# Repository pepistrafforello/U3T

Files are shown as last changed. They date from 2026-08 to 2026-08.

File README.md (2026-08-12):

# U3T — the Unnamed 3D Thingy

**A parametric generator, and its own verification suite, for a family of two-part solids that
look impossible from every side and come apart with a single movement.**

> There is a block made of two different kinds of wood, mated so perfectly that there is no air
> between them. From every side the assembly looks exactly the same: a seam at mid-height with a
> small dovetail key in the middle of each face. The two layers can be separated with one simple
> movement — no glue, no springs, no tricks. The same movement puts them back together. How?

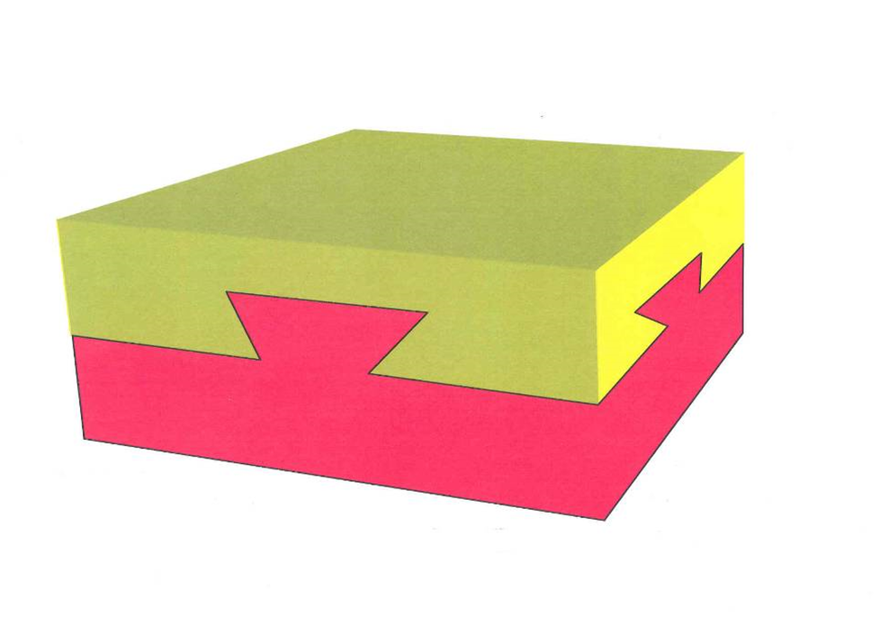
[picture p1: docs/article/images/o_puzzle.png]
The block, identical from all four sides


The dovetail on the front face says the top cannot be lifted. The dovetail on the side face says it
cannot slide sideways either. Every face you check makes the object more impossible — and yet the
answer is not unique: the puzzle has *infinitely many* solutions, and the interesting ones have
enough room left over to hide a message inside.

This repository holds the code that designs those objects, the code that proves the design is
correct, the print-ready STL files it produces, and the write-ups. The story is told in the
article: [`docs/article/medium-post.md`](docs/article/medium-post.md). The engineering is in
[`docs/The-Unnamed-3D-Thingy.md`](docs/The-Unnamed-3D-Thingy.md).

---

## The idea in one move: shear the world

Suppose the two halves separate by sliding along a fixed oblique direction **d** = (d₁, d₂, 1).
When is a proposed parting surface valid? Change coordinates so that **d** becomes vertical:

```
u = x − d₁·z        v = y − d₂·z        z = z
```

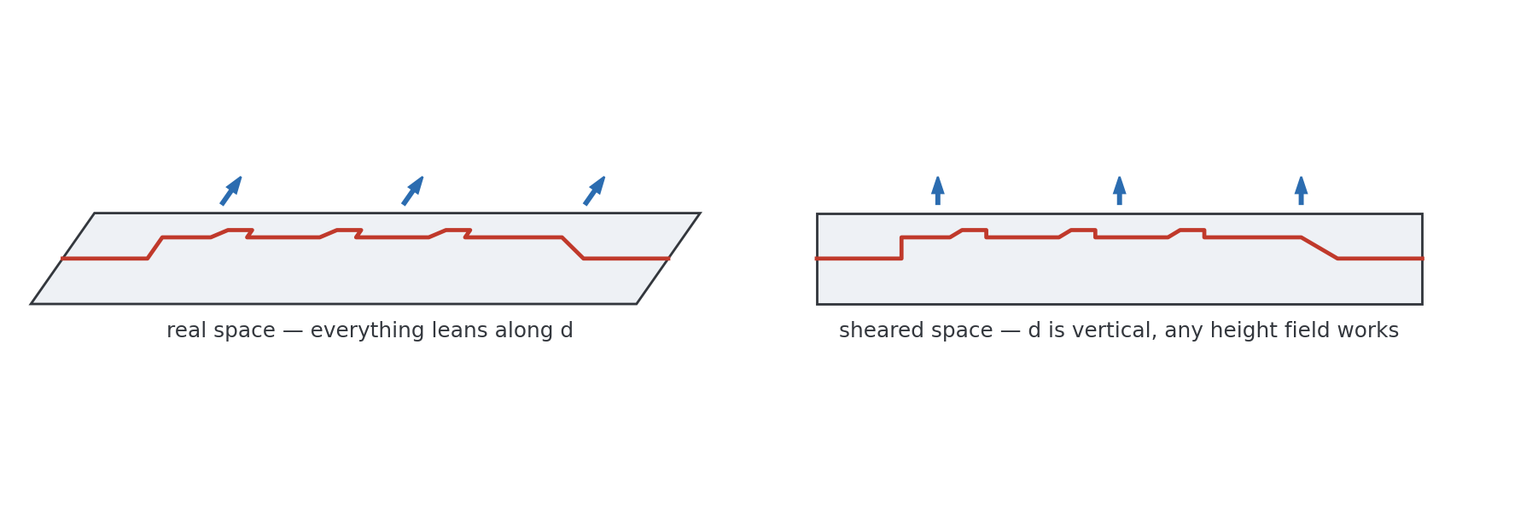
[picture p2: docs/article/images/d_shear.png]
The shear trick


In sheared space the separating motion is straight up, and a surface can be lifted off vertically
**exactly when it is a single-valued height field** — one z per (u, v), vertical cliffs allowed.
So: draw *anything* in the (u, v) plane, extrude it vertically, shear back. The walls come out
parallel to **d** automatically, and the two parts are separable by construction. No angle checks,
no trial and error.

Two consequences fall out of that one sentence:

* **Every side gets its own private groove.** Because **d** has a component along all three axes,
  each face carries an independent ramp instead of two grooves crossing the whole block — so the
  square is not special: any polygon with three or more sides works.
* **The middle of the block becomes free real estate.** Once the perimeter does the puzzle's work,
  the rest of the hidden interface can be arbitrary artwork: a title, a portrait, a QR code.

The shipped object uses that space for a graduation gift — a title, a subtitle, and a scannable QR
code, none of it visible from outside:

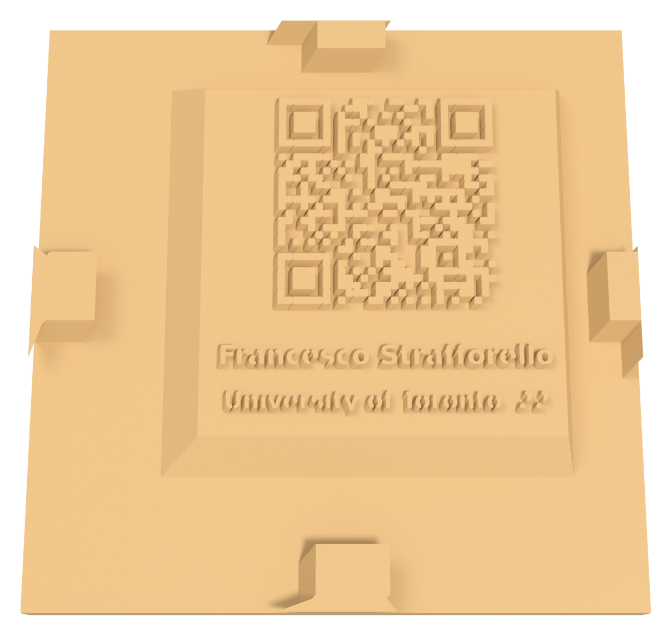
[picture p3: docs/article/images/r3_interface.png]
The hidden interface


---

## What is in this repository

```
u3t_generator.py        straight edition: builds both parts, then verifies them
u3t_rot_generator.py    rotation edition: same contract, opens by rotating about an external axis
dfm_scan.py             independent minimum-feature scan (the 0.5 mm FDM rule)
u3t_figures.py          figures for the technical document, straight edition
u3t_rot_figures.py      figures for the technical document, rotation edition

stl/                    the six meshes: two printable pairs, plus assembly-oriented copies
verification/           machine-readable verification reports (JSON), regenerated on every build

docs/
  The-Unnamed-3D-Thingy.md    the full write-up: theory, Fusion walkthrough, generator,
                              verification, printing, and the rotation chapter
  original-design-notes.pdf   the notes the project started from, years before it was finished
  figures/                    figures for the write-up (original/ = extracted from the PDF)
  article/medium-post.md      the article, in Medium's voice
  article/images/             its renders (Blender/Cycles) and diagrams (matplotlib)

tools/
  prep_shots.py           poses the verified STLs and emits the shot list
  blender_render.py       headless Cycles renderer for the photographic figures
  postprocess.py          flatten / crop / montage / sanity-check the renders
  diagrams.py             the clean 2D diagrams used by the article
  make_paste_html.py      article markdown -> HTML page you can paste into Medium
  extract_pdf_figures.py  re-extracts docs/figures/original/ from the PDF
```

Everything writes into `build/` (git-ignored) except the deliverables — STLs, reports, figures —
which land in their committed locations.

---

## Quick start

```bash
git clone https://github.com/pepistrafforello/U3T.git
cd U3T
python -m venv .venv
.venv\Scripts\activate          # Windows;  source .venv/bin/activate elsewhere
pip install -r requirements.txt

python u3t_generator.py         # straight edition: build + verify        (~10 s)
python u3t_rot_generator.py     # rotation edition: build + verify        (~25 s)
python dfm_scan.py              # minimum-feature scan of all four parts  (~45 s)
```

Each generator writes its STLs to `stl/`, its report to `verification/`, and prints the whole
verification suite as it goes:

```
bottom: watertight=True winding=True bodies=1 volume=89932 mm^3 ... -> PASS
top:    watertight=True winding=True bodies=1 volume=56138 mm^3 ... -> PASS
assembled overlap: 0.000000 mm^3 -> PASS
slide along d, t= 0.05: overlap=0.000000 -> PASS
...
slide along d, t=   40: overlap=0.000000 -> PASS
control (straight up), t=1.0: overlap=61.126 mm^3 -> PASS (locks)
control (flat diagonal slide), t=1.0: overlap=341.060 mm^3 -> PASS (locks)
```

Nothing else is needed to print the object — but if you want to regenerate the pictures too, see
[Reproducing the figures](#reproducing-the-figures-and-the-article).

---

## The two editions

Both are 100 × 100 × 15 mm, both show the identical dovetailed seam on all four faces, and both
hide the same interface. They differ only in the motion that opens them — which is the point: two
objects that are indistinguishable from the outside and refuse each other's solution.

| | straight edition | rotation edition |
|---|---|---|
| opening motion | translation along **d** = (0.7, 0.7, 1) | rotation of ≈ 12° about an external axis |
| axis / direction | 44.7° off vertical, diagonal in plan | direction (1, 1, 0)/√2 through (105, −105, −103.5) mm |
| walls | planar, parallel to **d** | patches of cylinders coaxial with the axis |
| generator | `u3t_generator.py` | `u3t_rot_generator.py` |
| print files | `stl/U3T_bottom.stl`, `stl/U3T_top_print.stl` | `stl/U3T_rot_bottom.stl`, `stl/U3T_rot_top_print.stl` |
| report | `verification/verify_report.json` | `verification/verify_report_rot.json` |

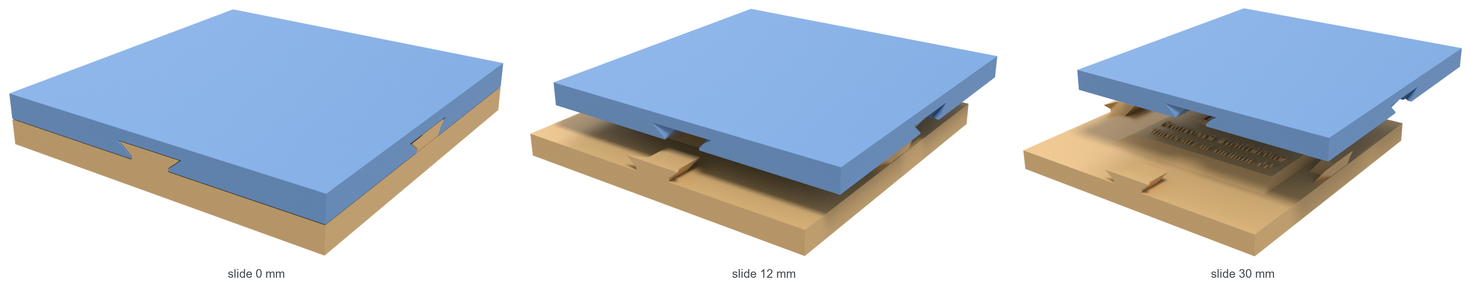
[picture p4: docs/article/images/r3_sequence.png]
Opening the straight edition


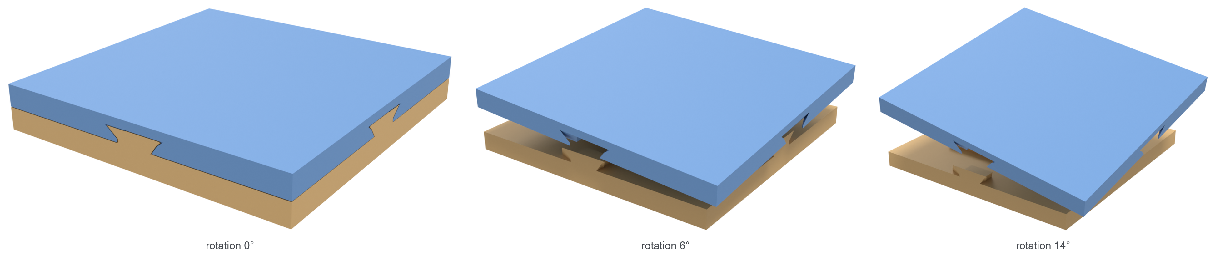
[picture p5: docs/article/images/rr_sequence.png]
Opening the rotation edition


The rotation edition needs three placement rules, all of which the generator's geometry satisfies
and the write-up derives:

1. the axis must run **diagonally in plan**, or orbit planes end up parallel to a face and grooves
   surface where they must not;
2. the **apex plane** — the vertical plane through the axis, where orbits turn around — must miss
   the block, otherwise a flat lid is visited twice by the same orbit and the parts jam (this is
   the silent failure that wrecked the original Blender attempt);
3. the axis must sit **far enough away** that every orbit slope stays printable.

---

## Design parameters

All of them live at the top of the generators, in millimetres. Change one, re-run, and the whole
object — including its proof — is rebuilt.

| parameter | shipped | meaning |
|---|---|---|
| `L`, `H` | 100, 15 | stock footprint and height |
| `SHX`, `SHY` | 0.7, 0.7 | the separation direction **d** = (`SHX`, `SHY`, 1) |
| `CLR` | 0.15 | clearance per part; total gap between the halves is 0.3 |
| `BAND_Z` | 7.5 | height of the seam on the side faces |
| `KEY_Z0`, `KEY_Z1` | 7.5, 11.5 | bottom and top of the dovetail key |
| `KEY_NECK_Z` | 8.3 | straight neck below the flare (manufacturability, see below) |
| `KEY_HW0`, `KEY_HW1` | 6.0, 10.0 | key half-width at the band and at the top (it flares → undercut) |
| `KEY_RAIL` | 8.0 | length of the internal anchor rail behind each key |
| `MIN_FEATURE` | 0.55 | minimum printable wall/stroke enforced on the interface artwork |
| `PLAT_*` | 7.0 … 11.0, ±30/34 | the plateau frustum that carries the payload |
| `QR_BOX`, `TITLE_BOX`, `SUB_BOX` | — | where the payload sits, in sheared plan coordinates |
| `QR_PAYLOAD`, `TITLE`, `SUBTITLE`, `SIGNATURE` | — | the content itself |

Two rules constrain the numbers, and both were learned the hard way:

* **Depth costs lean.** A key `h` mm tall can protrude at most `lean × h` from the face. A
  near-vertical **d** gives wafer-thin keys no matter how you draw them. At 0.7 the design sits
  right at the 45° overhang limit an FDM printer will bridge without supports — which is exactly
  where you want to be.
* **Anchor whatever the crop can orphan.** Each key continues inward as a solid rail, unioned in
  *before* the stock box crops the leaning prism. Skip this and the visible tabs become watertight,
  collision-free, and attached to nothing.

### Making your own

```python
# u3t_generator.py
QR_PAYLOAD = "https://example.com/album"   # shorter URLs -> coarser, easier-to-print modules
TITLE      = "Your Name"
SUBTITLE   = "Your Occasion"
```

then `python u3t_generator.py`. The verification suite re-runs on the new geometry, so a change
that breaks the puzzle property cannot pass silently. For a different polygon, edit the `faces`
table in `key_footprints()` — one entry per side, each with its inward plan direction; the theory
imposes no limit on the number of sides.

---

## Verification: the printed object cannot be flawed by luck

"Be accurate" means *do not trust the construction* — test the meshes that go to the printer. Each
generator attacks its own output before it exits, and writes the results to `verification/`.

| check | straight edition | rotation edition |
|---|---|---|
| bottom part watertight, consistent winding | yes — 89 932 mm³ | yes — 88 380 mm³ |
| top part watertight, consistent winding | yes — 56 138 mm³ | yes — 57 572 mm³ |
| **connected bodies per part** | 1 and 1 | 1 and 1 |
| assembly envelope | exactly 100 × 100 × 15 | exactly 100 × 100 × 15 |
| assembled overlap | 0.000000 mm³ | 0.000000 mm³ |
| overlap through the full opening motion | 0.000000 mm³ at 14 stations, t = 0.05 … 40 mm | 0.000000 mm³ at 12 stations, θ = 0.05° … 25° |
| **control** — pull straight up, 1 / 2 mm | collides: 61.1 / 102.8 mm³ | collides: 128.5 / 227.6 mm³ |
| **control** — flat diagonal slide, 1 / 2 mm | collides: 341.1 / 863.3 mm³ | collides: 416.3 / 926.1 mm³ |
| **control** — the *other* edition's move | — | collides: 282.1 mm³ (straight slide, 2 mm) |
| **control** — reverse rotation, 1° | — | collides: 21 424 mm³ |
| thin-feature scan (`dfm_scan.py`) | no free-standing feature below 0.5 mm | no free-standing feature below 0.5 mm |

The control rows are the puzzle property itself, measured rather than asserted: the naive motions
jam, and the one intended motion sweeps through the entire disassembly without ever touching. The
body-count row exists because it once failed — an early draft with a shallower **d** and no anchor
rails produced keys that were watertight, collision-clean, and *detached*. Watertightness says
nothing about a mesh being in one piece; counting connected components does.

---

## Manufacturability

Geometry can be provably correct and still contain features no nozzle can make. After a
manufacturability review flagged two of them, the generators enforce a minimum-feature policy:

* **Asymmetric clearance on the artwork.** A sliding fit does not need the gap split evenly. The
  raised side keeps its full nominal stroke width (never below `MIN_FEATURE` = 0.55 mm) and the
  cavity absorbs the whole 0.3 mm — otherwise the wall left standing between two neighbouring
  letter cavities can shrink to a tenth of a millimetre. Residual sub-minimum necks are removed by
  a morphological opening; sub-minimum walls between adjacent cavities are fused by a closing
  (`clean_thin`, `close_gaps`, `content_offset` in `u3t_generator.py`).
* **A straight neck under every flare.** The key lip starts only above `KEY_NECK_Z`, where its own
  depth already exceeds 0.55 mm, so the overhanging lip never feathers to nothing at its root.

`dfm_scan.py` re-checks this the way a print shop does — slice the part every 0.45 mm, erode each
slice by 0.249 mm, and report whatever disappears:

```bash
python dfm_scan.py
```

Both top parts come back completely clean. The bottom parts report a handful of patches, all of
them on the sloped edges where the key flanks meet the outer faces: those are tapering edges of
solid material, backed by full-thickness material immediately behind — a chamfer, not a wall. They
print as a slightly rounded lip edge, with no consequence for fit or strength. Every flush dovetail
outline in this family has them.

---

## Printing and assembly

* **Files** — print `stl/U3T_bottom.stl` as oriented and `stl/U3T_top_print.stl` (already flipped
  exterior-side-down); or the `U3T_rot_*` pair for the rotation edition. `U3T_top.stl` and
  `U3T_rot_top.stl` are the assembly-oriented copies, for CAD and inspection.
* **No supports.** The leaning walls sit at 44.7°, right at the classic FDM limit; the ramps are
  gentler; every relief faces up on the bed.
* **Settings** — PLA, 0.2 mm layers (0.12 mm makes a crisper QR), 3 perimeters, ≥ 15 % infill.
  Enable elephant-foot compensation (~0.1 mm) or deburr the first-layer edges: the band and the
  side faces have to mate flush.
* **Fit** — the 0.3 mm total gap is a snug sliding fit on a well-tuned printer. If it binds, sand
  lightly or rebuild with `CLR = 0.20`; for a loose demonstration fit use `CLR = 0.25`.
* **Assembly** — rest the top over the bottom offset by about +10 mm in x and y and lower it along
  the diagonal; it seats flush in one push. Because the lean of **d** breaks the square's symmetry,
  **only one of the four orientations engages** — the solver has to find the motion *and* the
  orientation.
* **The reveal** — relief QR codes scan best under raking light; a soft pencil rubbed flat across
  the module tops makes them scan instantly.

---

## Reproducing the figures and the article

The diagrams are matplotlib; the photographic figures are rendered headlessly in **Blender 5.x**
with Cycles, which has to be installed separately and reachable as `blender`.

```bash
python tools/diagrams.py                  # the 2D diagrams -> docs/article/images/
python tools/prep_shots.py                # pose the STLs -> build/posed, build/shots.json
blender -b --factory-startup -noaudio --python tools/blender_render.py -- \
        build/shots.json build/render_raw
python tools/postprocess.py               # flatten, crop, montage, check -> docs/article/images/
python tools/make_paste_html.py           # -> build/medium-post-paste.html
python u3t_figures.py                     # technical-document figures -> docs/figures/
python u3t_rot_figures.py
```

`postprocess.py` finishes with an automated check on every emitted image (minimum width, and a
non-white content fraction inside sane bounds) and prints `BAD: none` when they all pass.
`make_paste_html.py` produces a local page whose rich-text copy-paste lands cleanly in Medium's
editor, images included.

---

## Documentation

| document | what it is |
|---|---|
| [`docs/The-Unnamed-3D-Thingy.md`](docs/The-Unnamed-3D-Thingy.md) | the complete write-up: the original notes, the proof, a step-by-step Autodesk Fusion walkthrough, the automated pipeline, the verification suite, printing, and the rotation edition |
| [`docs/article/medium-post.md`](docs/article/medium-post.md) | the same story told as an article, for readers rather than builders |
| [`docs/original-design-notes.pdf`](docs/original-design-notes.pdf) | where it began: the unfinished notes, kept for provenance |

---

## Tested environment

Python 3.11.5 on Windows 11, with the versions pinned as comments in
[`requirements.txt`](requirements.txt). The heavy lifting is done by
[`manifold3d`](https://github.com/elalish/manifold) (guaranteed-watertight booleans),
[`trimesh`](https://github.com/mikedh/trimesh) and [`shapely`](https://github.com/shapely/shapely).
Nothing in the pipeline is platform-specific; the only external program is Blender, and only for
the figures.

## License

Apache License 2.0 — see [`LICENSE`](LICENSE). A small number of screenshots inside the original
design notes are third-party material and are excluded from that grant; they are itemised in
[`NOTICE`](NOTICE), together with the acknowledgements this project owes.

*The object still has a dovetail on every face, a motion nobody can see, a name hidden in the
middle — and, after all this time, no name of its own.*

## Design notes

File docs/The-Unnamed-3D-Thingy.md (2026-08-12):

# The Unnamed 3D Thingy

*Design notes — completed edition. Parts 1–4 are the original notes (text unchanged, figures re-extracted).
Parts 5–13 complete the project: the theory of why the construction works, a verified reference design,
step-by-step instructions for Autodesk Fusion, an automated generator, and print-ready STL files that have
been checked for correctness by simulation.*

---

## Part 1 — The puzzle (original notes)

Years ago, my boss shared with me a book he wrote, in digital format; its main topic is critical
thinking training. There is a section about a mental exercise, that I am summarizing as follows:

There is a block composed of two different types of wood, each about an inch in height, that
were mated in a manner that ensured no gaps of air between them. From every side, the
assembly looks the same:

The block, identical from every side

The two layers of wood can be separated from each other by a single simple movement, there
is no glue or any other adhesive or mechanical inhibitor involved. They could be reunited with
the same type of motion.

In the book, the solution to this puzzle is exactly the one beautifully designed by Roger:

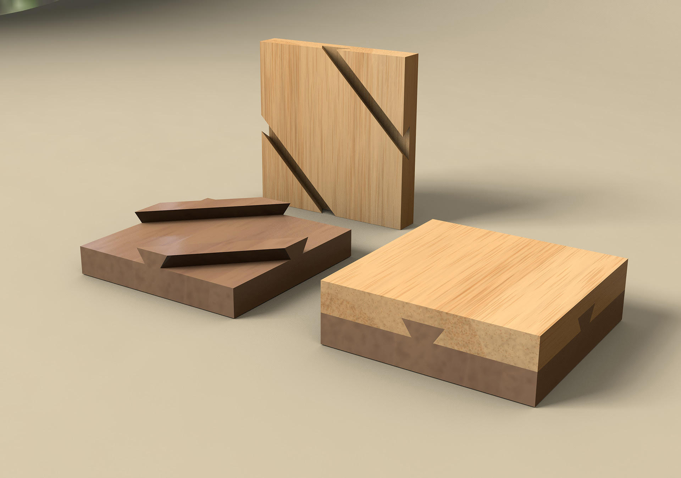
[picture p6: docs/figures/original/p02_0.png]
Roger's solution, exploded


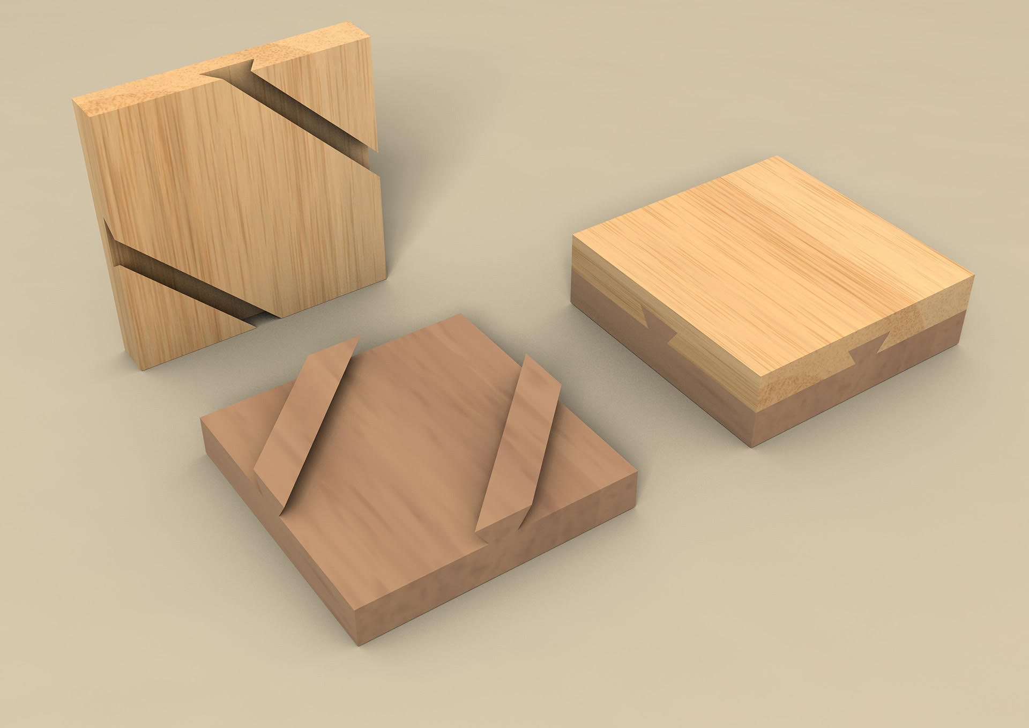
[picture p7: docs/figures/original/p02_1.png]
Roger's solution, second view


(I really love it!)

My observation back then, which I rummaged a bit more over time, is that this is not *the
solution*, because in fact the problem admits infinite solutions. To prove it, I created a different
one using 3D Builder on Windows, I had it 3D printed and gave it to my boss around Christmas
as a "semi-parting" gift, as he is semi-retiring:

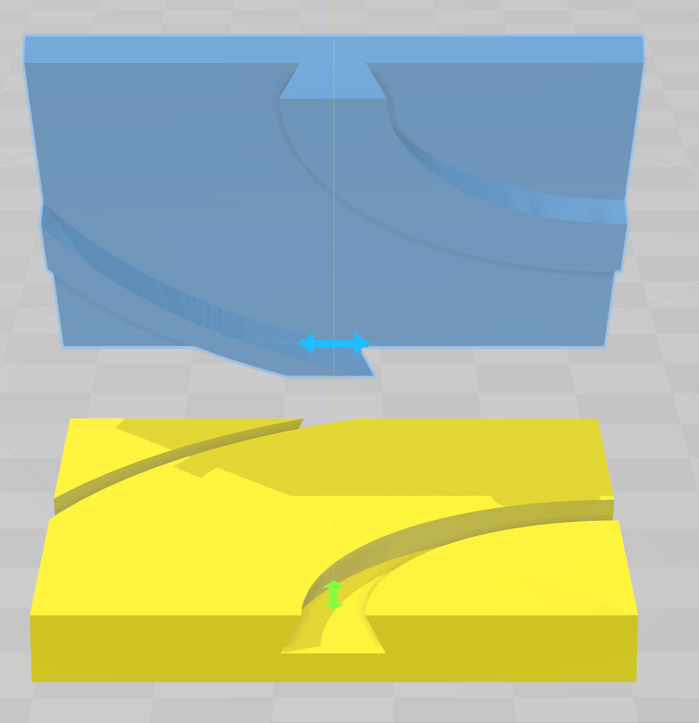
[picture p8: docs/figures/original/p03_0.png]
My curved-groove solution


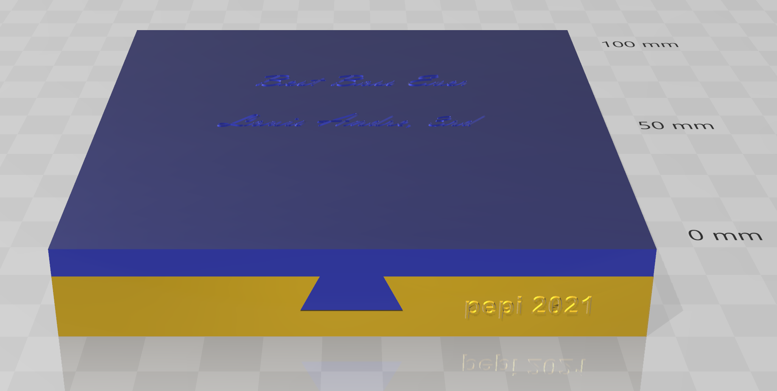
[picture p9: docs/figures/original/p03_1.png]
The printed gift, assembled


As it can be easily verified, Roger's solution and mine belong to a family of solutions which
consist of two grooves each connecting one of the side keys to another, where the center of the
curve that they describe can be arbitrarily set from somewhere between the middle of the
square and one of the corners, then to a corner (as in my solution), then beyond the corner
all the way to infinity (Roger's solution).

There are of course infinite solutions in this family, but they are still very much limited in their
shape; in particular, there is no additional information that can be encoded in the shape itself.

## Part 2 — The generalized method (original notes)

After giving it a bit of thought, I found out that we can do much better than that.
In fact, any amount of information, such as, for instance, QR codes or Roger's portrait, can be
encoded *inside* the apparatus without violating the requirements. Furthermore, the method can
be extended from four to any number of sides ≥ 3.

In a nutshell, the process is as follows:

- define a base shape for the half side *(original image lost from the PDF — see the dimensioned
  profile in Part 7, which plays the same role)*
- mirror it to generate a full side
- compose the sides to build the "polygon box" of choice, a square in this example but of
  course it can be anything ≥ 3

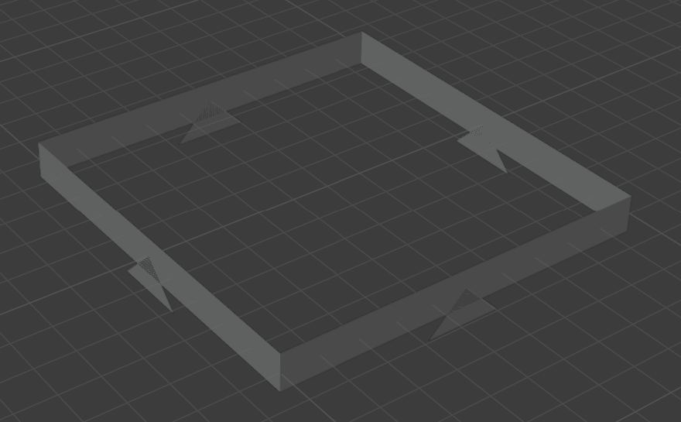
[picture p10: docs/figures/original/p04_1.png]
The polygon box


- extrude the box along a line with constant curvature, which can be arbitrary with some
  constraints, e.g. it cannot lie on a plane that is parallel to any of the sides. In this
  example, the extrusion is carried out along a straight line that is not parallel to any of the
  axes of the square prism, but it could be any other from an infinity of possible curves

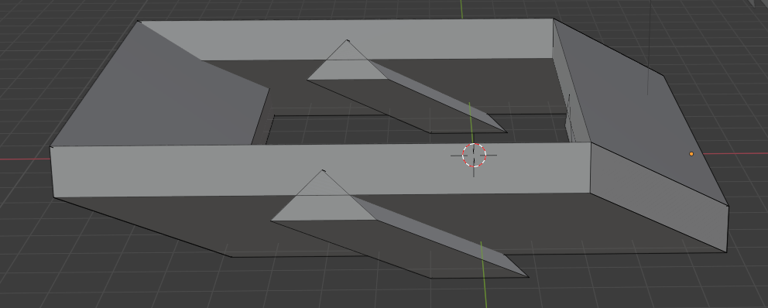
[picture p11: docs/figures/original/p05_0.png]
The extruded box


- compose the 3d boundary box for the complete assembly, that is, a prism that matches
  the contour of the "polygon box" and extends to surround the volume of the missing
  element
- crop the extrusion using the boundary box

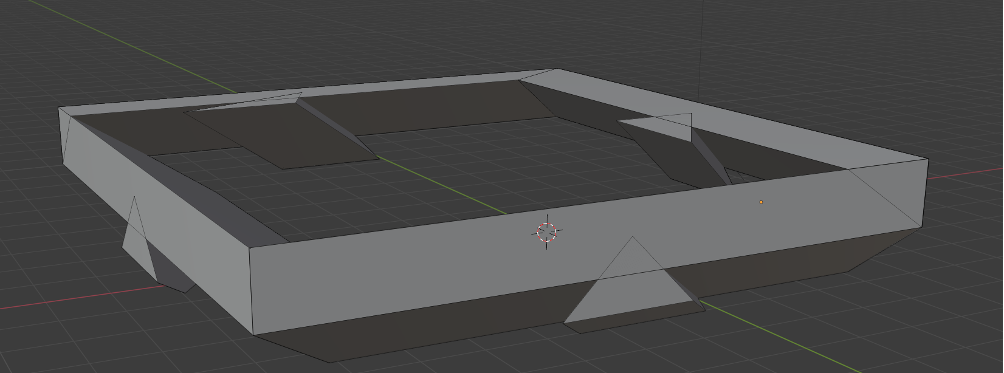
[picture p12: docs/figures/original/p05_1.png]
The cropped extrusion


Now, all the mandatory features are implemented; all we are left to do is to place a "lid" on top of
the box, and then create the complementing part by filling the space below. That means that we
still have a lot of degrees of freedom in designing the rest of the boundary between the two
parts, and thus we could encode an arbitrary amount of information there.

The key difference between this method and the solutions mentioned at the beginning of the
document is that, by moving along three axes instead of two, we were able to give each side its
own independent groove, which in turn makes it possible to change arbitrarily the number of
sides.

Putting it all together, I built a quick complete example using Blender up to the step above, and
then assembling it with 3D Builder, using .stl for the exchange:

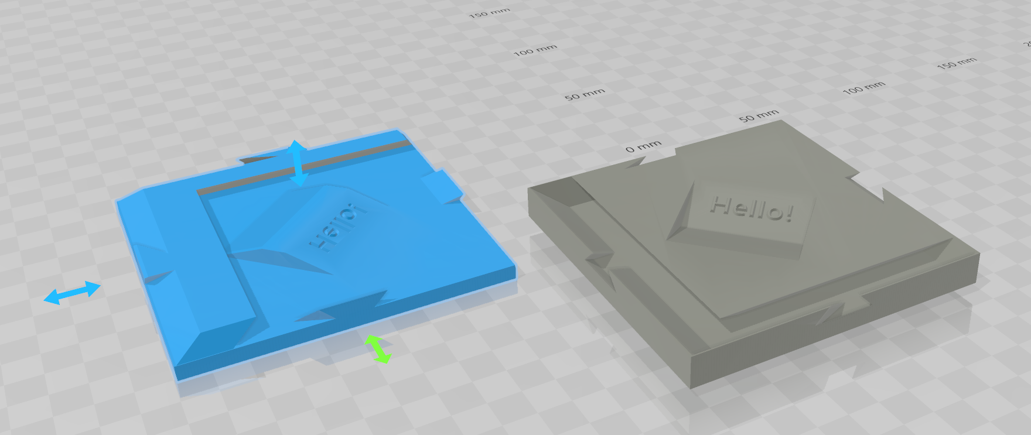
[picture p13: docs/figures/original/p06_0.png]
Hello example, parts


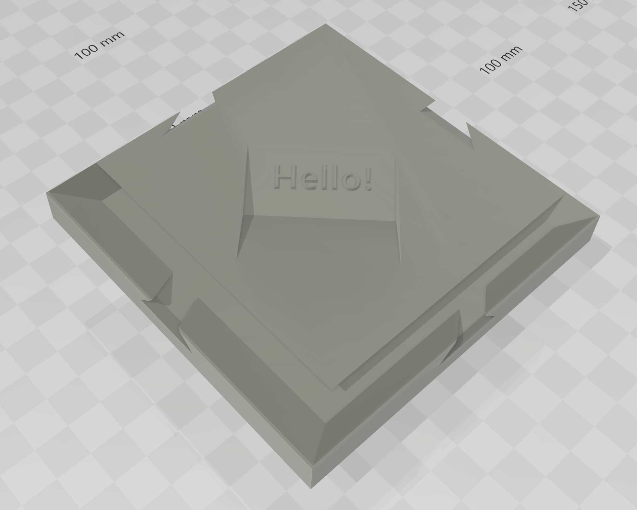
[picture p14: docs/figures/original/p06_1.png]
Hello example, assembled


## Part 3 — A graduation U3T ("Unnamed 3D Thingy") for Francesco (original notes)

Based on the above, we have a little project for the upcoming graduation in the family — I know, it
sounds impossible! I wonder, could it be reused elsewhere? ;)

The basic idea: starting from the "Hello" design in the previous page, adding two enhancements:

- Carrying out the extrusion of the "polygon box" along a nice, creative curve instead of a
  predictable and boring straight line
- Maximize use of the available space in the box, including the following elements:
  - A nice title "Francesco Strafforello"
  - Subtitle "University of Toronto '22"
  - QR code (will point to a family album online)
  - (only if feasible) other cool geometric elements TBD
- To account for engineering tolerance, we create two slightly different matrices, inner and
  outer (I'd rather stay out of gender references)

**1 — matrix.** The dimensions of the final product will be mm 100×100×15. Construct using 3D Builder.

Tolerance guidance (from Xometry handbook):

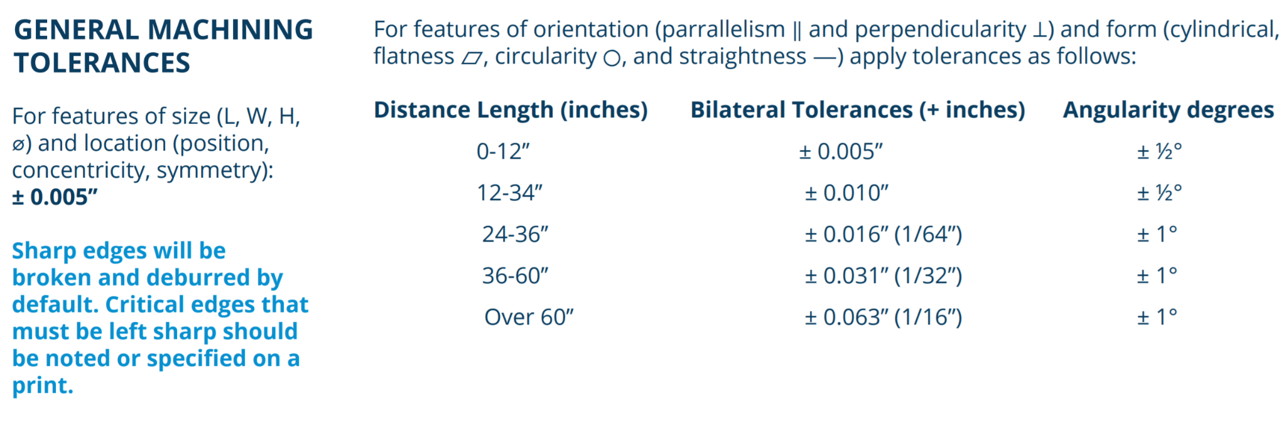
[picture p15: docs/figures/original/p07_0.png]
Xometry general machining tolerances


Given the dimensions of our project, it seems that applying a tolerance of ± 0.005" = 0.127 mm
everywhere might work.

To introduce tolerance, we modify the construction process described above. While we were
going through the extrusion process for one of the mating parts, and filling the remaining space
to obtain the other one, now we are going to extrude the tolerance space, and then using the
free space on either side to obtain the actual parts. With that in mind, we start by creating the
matrix as the difference between the inner and the outer one.

Inner matrix:

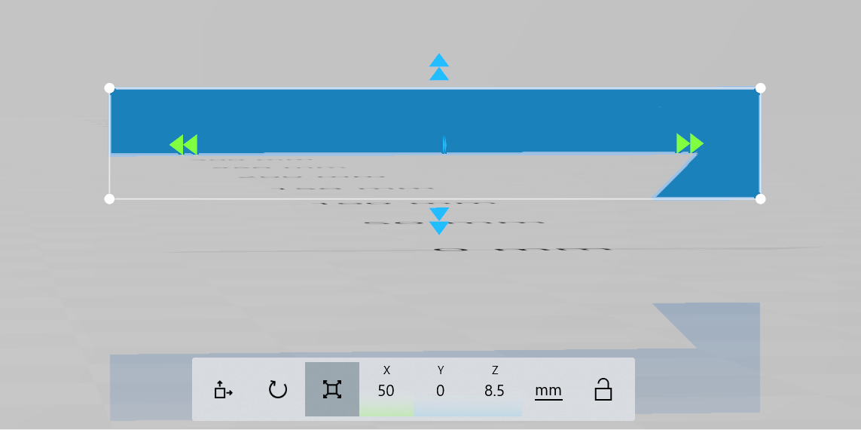
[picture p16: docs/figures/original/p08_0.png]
Inner matrix


Outer matrix:

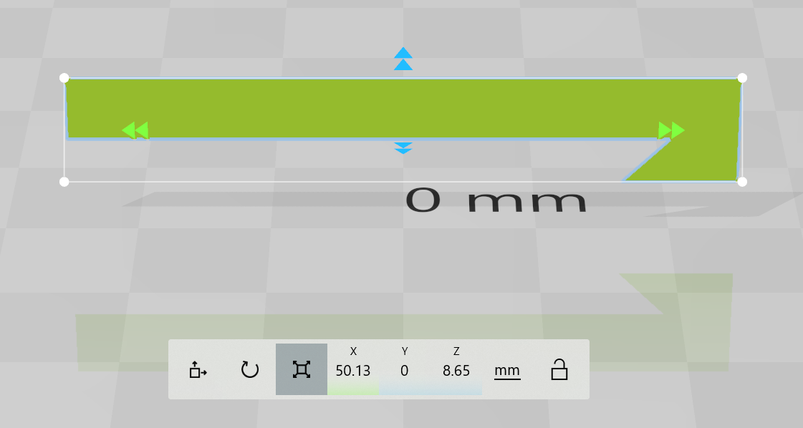
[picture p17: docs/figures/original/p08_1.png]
Outer matrix


The difference in the longer side (0.15 instead of 0.127) is adopted to make extra room for
diagonals and various curves.

In the end, the new matrix is simply composed of three thin rods joined together:

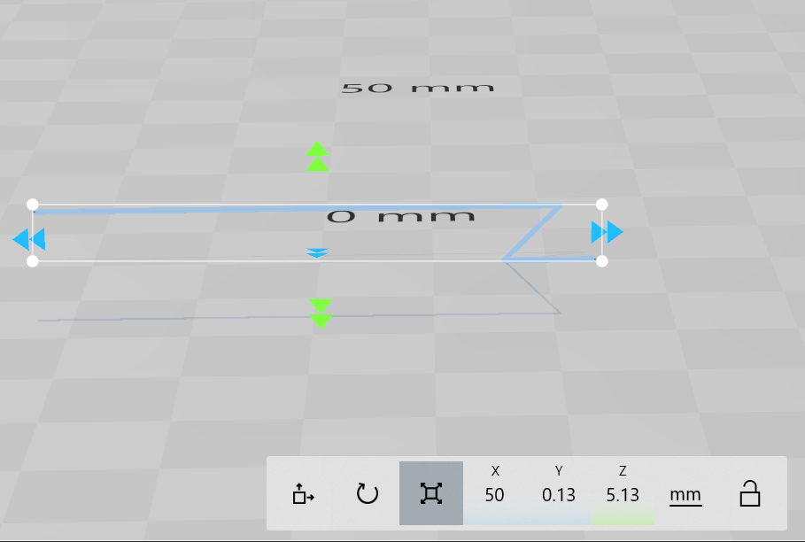
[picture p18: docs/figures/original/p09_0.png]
Matrix rods


And this is our "polygon box" — that is, the apparatus before the extrusion:

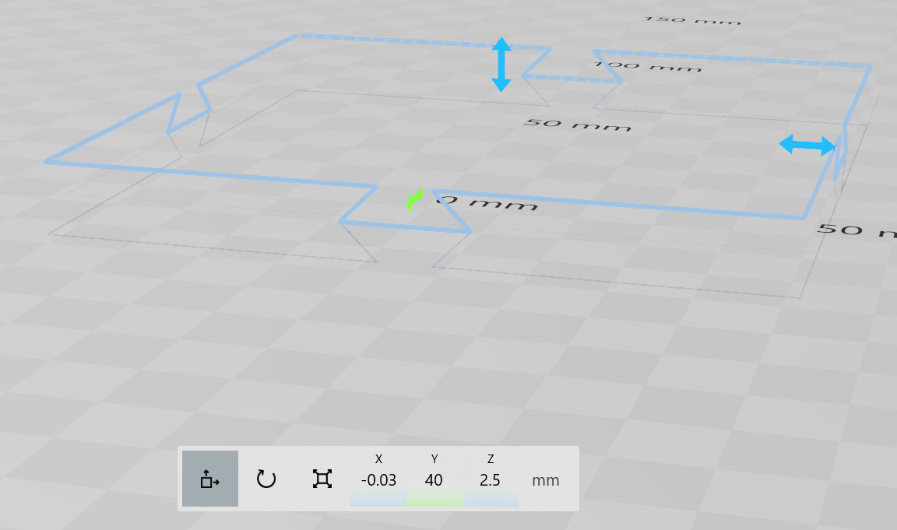
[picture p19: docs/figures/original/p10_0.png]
Polygon box wireframe


## Part 4 — The Blender attempt (original notes)

Thus far, I have used 3D Builder. Now I export the model in .STL format, to perform the
extrusion with Blender. After a few attempts, I found that rotating the polygon box and applying
the screw modifier along an external object I could get a nice, curved surface (external object is
the elongated cuboid in the background):

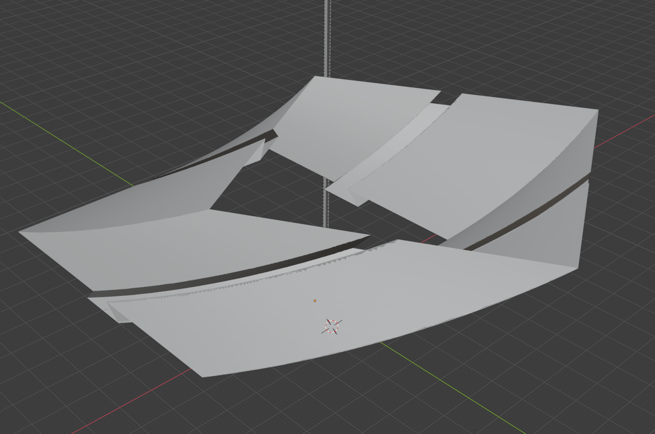
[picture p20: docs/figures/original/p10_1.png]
Screw-modifier extrusion in Blender


After exporting the component to .stl, and importing it back to Builder 3D we can obtain this
scene:

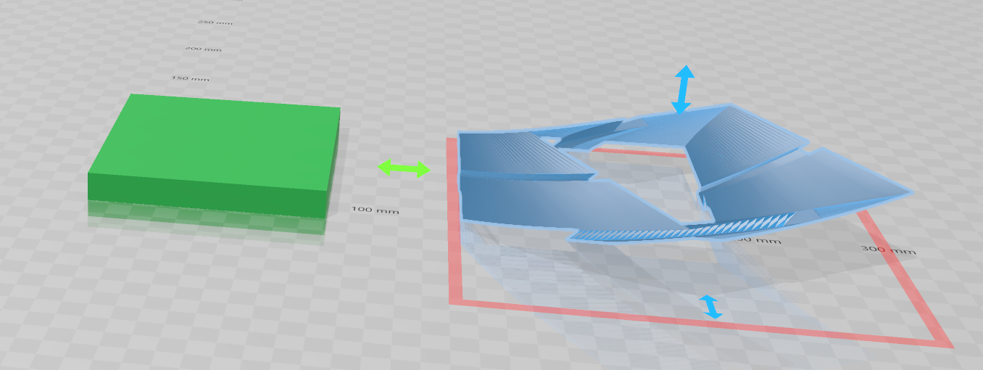
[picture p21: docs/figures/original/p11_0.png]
Back in 3D Builder


The green cuboid is the final volume for the apparatus, the blue one is the imported artifact.
Note the red square around it, something in its geometry seems to be problematic for 3D
Builder; but, activating the "Repair" function actually alters its geometry. I'm trying to go ahead
as it is, everything seems to be working so far. Checking out the intersection of the two artifacts:

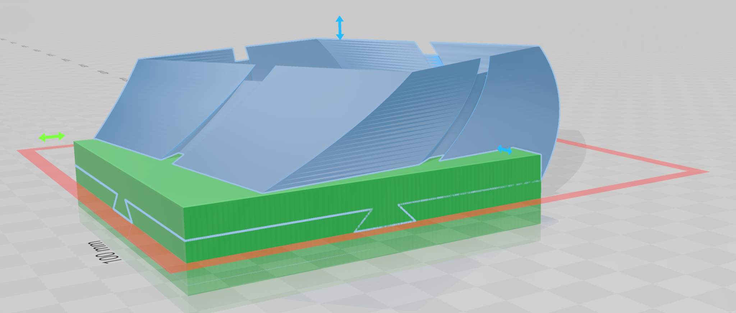
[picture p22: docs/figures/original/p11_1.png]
Intersection check


Everything seems to be correct from the opposite side as well:

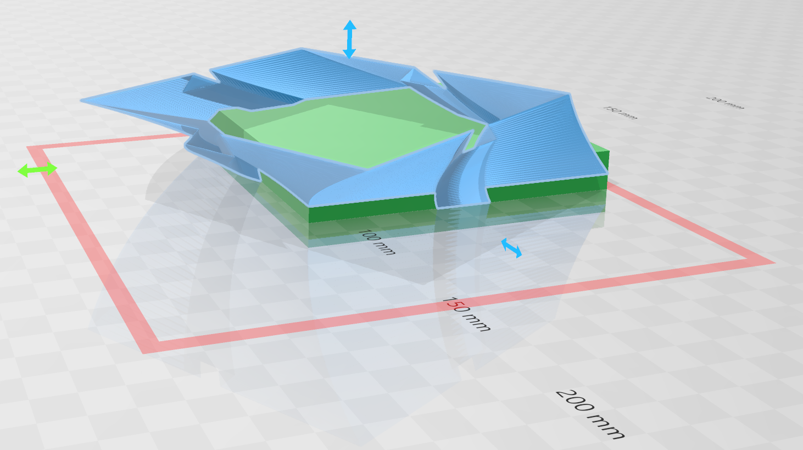
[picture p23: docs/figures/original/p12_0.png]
Opposite side check


Next step: I need to add a bottom to my "cutting box" — the blue shape, that is.
The bottom is where I want to add some hidden information — in this case, a QR code pointing to
Francesco's LinkedIn profile. I generated the QR code using QRmonkey.org, but I could have
used the sharing feature in Chrome, etc., then I loaded it in 3D Builder and gave it a bit of 3D
relevance (see https://www.youtube.com/watch?v=plvNbWHi84Y)

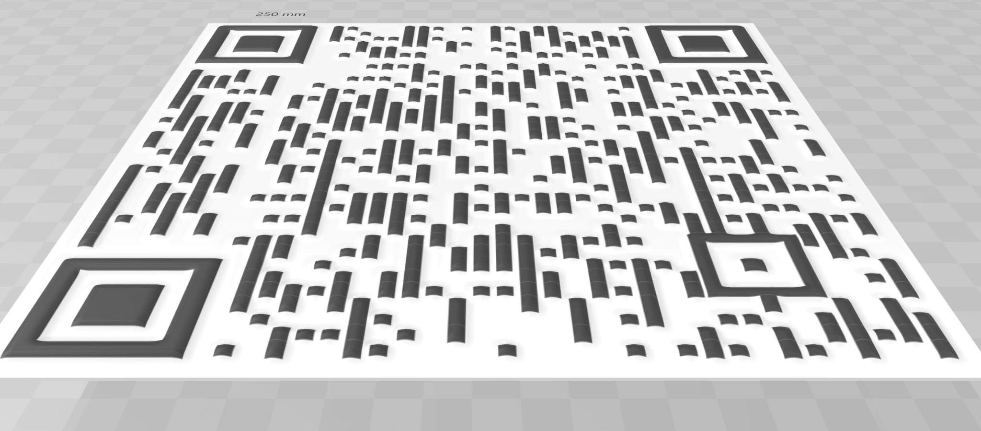
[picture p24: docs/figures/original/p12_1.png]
QR code with relief


I am making sure that the angles of the 3D features in the bottom QR-code image need to be
flatter than whatever angles will come from the "cutting box":

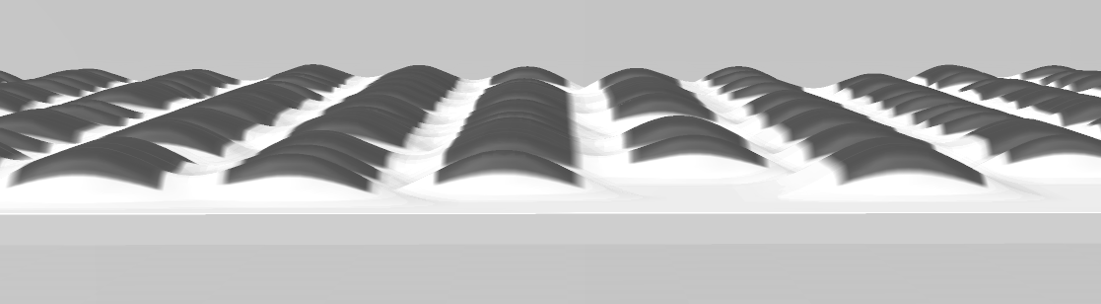
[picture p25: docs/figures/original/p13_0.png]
QR relief profile


Working inside 3D Builder I was able to join the bottom with the QR code and the cutting artifact,
but I could not manage to cleanup the material in excess from the bottom:

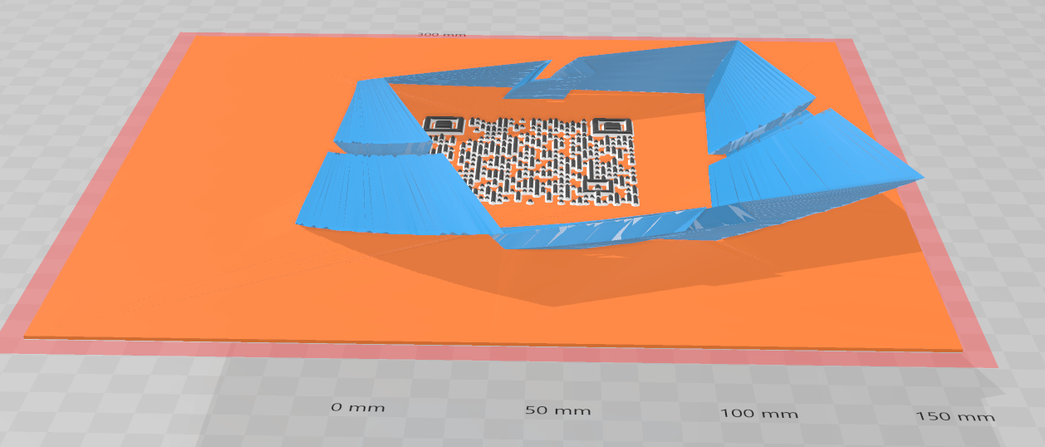
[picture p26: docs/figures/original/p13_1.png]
Excess material problem


So I exported the shape to STL and loaded it in Blender.

Then, with some hours of mesh work in Blender, I completed the cutting box which now includes
the bottom with QR code:

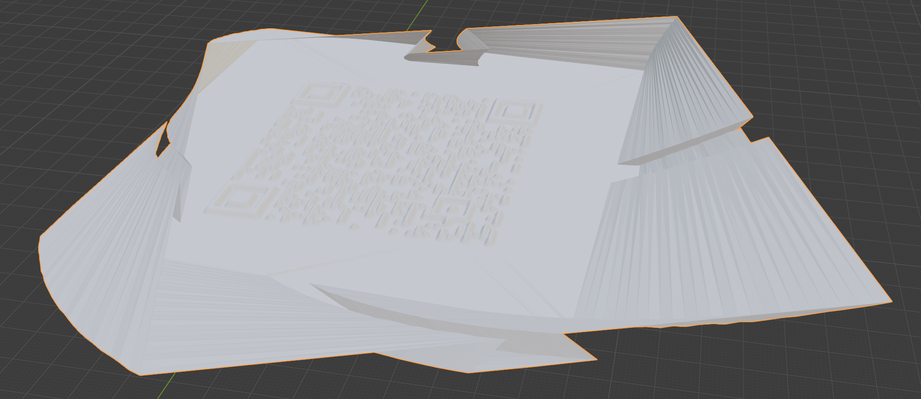
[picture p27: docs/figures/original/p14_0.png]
Completed cutting box


Since this shape has been entirely generated using a base shape that has a slightly larger width
than the known material tolerance, I can hope that removing it from the base box I will get two
mating parts; of course, the mesh is always an approximation but I can hope that in the worst
case I'll have to sand them a little.

OK, I'm saving this one just because I think it is cool:

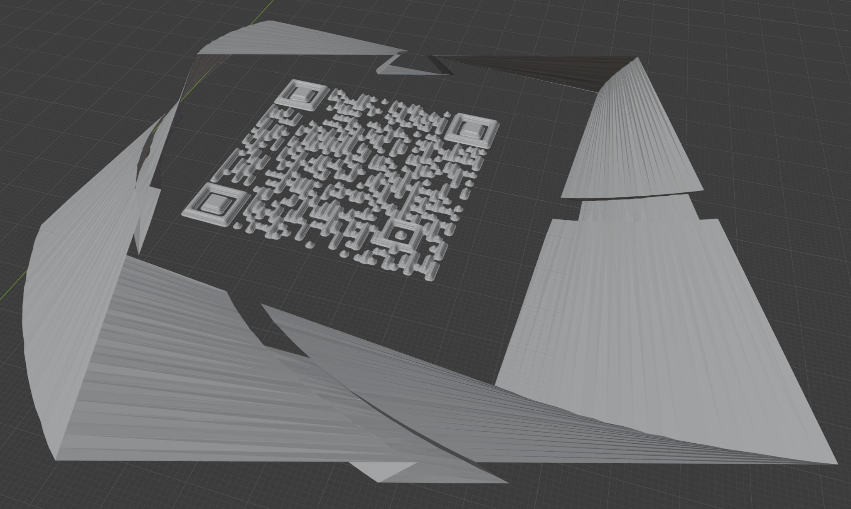
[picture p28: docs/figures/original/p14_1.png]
The cool one


---

*The notes stopped here. Everything below completes them.*

---

## Part 5 — What was still missing

The notes ended with a cutting box that "should" work, plus three open problems:

1. **No proof.** "I can hope that removing it from the base box I will get two mating parts" — hope,
   not verification. Nothing guaranteed that the two parts actually separate with one movement,
   or that they even come out as two valid solids.
2. **Fragile pipeline.** The Blender screw modifier produces an *open* surface (its ends are not
   capped), which is why 3D Builder drew the red warning frame and why "Repair" altered the
   geometry: repair tools cap and re-mesh non-manifold shells, changing the shape in the process.
   Hours of manual mesh work sat between the idea and a printable object, and every manual step
   could silently break the mating property.
3. **A hidden geometric trap.** The rule of thumb "features in the bottom must be flatter than
   whatever angles come from the cutting box" is necessary but **not sufficient** — see Part 12.
   With the screw-swept box of Part 4, a *flat* QR bottom is in fact not exactly separable near the
   plane through the screw axis; that is the subtle reason the manual assembly kept feeling harder
   than it should have been.

The completion below replaces hope with a construction that is correct *by construction*, and then
double-checks the result by simulating the disassembly motion on the final meshes.

## Part 6 — Why it works: one rule, one trick

**The rule.** Suppose the two parts separate by translating the top part along a fixed direction

> **d** = (d₁, d₂, 1)   (for example d = (0.7, 0.7, 1), about 45° off vertical)

Then the whole boundary between the two parts — the *parting surface* — must be visible "from
direction **d**": every straight line parallel to **d** must cross it at most once (crossing it along a
whole segment is also fine — that is a wall parallel to **d**, a sliding face). If some line parallel to
**d** entered the bottom part, left it, and entered it again, the top part would hook into the bottom
part and no translation along **d** could free it.

**The trick.** Instead of checking that rule surface by surface, change coordinates so it becomes
trivial. Define the **sheared coordinates**

> u = x − d₁·z    v = y − d₂·z    (z unchanged)

This shear maps every line parallel to **d** to a *vertical* line. So the rule becomes: *in sheared
coordinates, the parting surface must be a single-valued height field z = F(u, v)* — any height
field, with jumps allowed (a jump becomes a wall parallel to **d**, i.e. a sliding face).

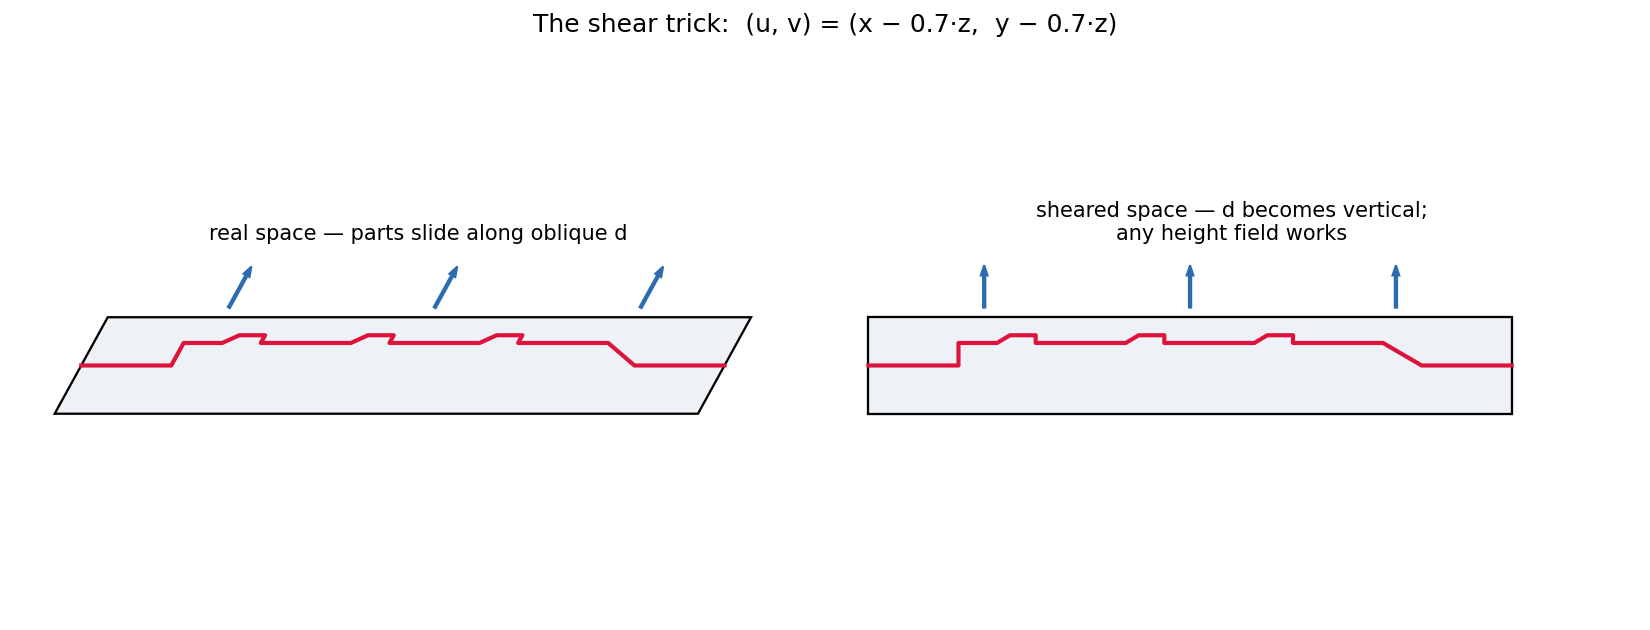
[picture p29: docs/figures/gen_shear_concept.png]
The shear trick


That single sentence is the entire theory of the U3T, and it proves the two claims from Part 2:

- **Arbitrary information can be encoded.** Any grayscale image whatsoever, interpreted as a
  height field in sheared coordinates, is a valid parting surface: QR codes, portraits, text —
  literally anything. Design your relief flat, shear it, done. In particular any artwork **extruded
  vertically in sheared space** (vertical walls become walls parallel to **d**) is separable *by
  construction* — no angle checking needed, ever.
- **Any number of sides ≥ 3 works.** The side keys are just more entries in the height field. The
  only constraint on **d** is the one already guessed in Part 2: **d** must not be parallel to any side
  face (its horizontal projection (d₁, d₂) must avoid the n side directions), so that every key
  actually withdraws *out of* its face instead of scraping along it.

And it explains the original two-groove family as the special case where the motion is horizontal
(a rotation about a vertical axis, or a straight slide as in Roger's): with no vertical component,
each groove must run all the way from one side to another, which is exactly why that family
carries no free space for information. Adding the third axis is what buys the freedom.

**Two robustness rules the height-field picture also gives us:**

- **Depth costs lean.** Anything that protrudes above the band *and shows on a side face* — the
  dovetail keys — can only be as deep (into the body) as `lean × height`: a key h mm tall can
  protrude at most `|(d₁,d₂)| × h` millimetres inward before the sliding motion would shear it
  off. A near-vertical **d** therefore produces wafer-thin keys no matter how they are drawn.
  With d = (0.7, 0.7, 1) and a 4 mm key, the tab is a solid ~2.8 mm deep — and 0.7 per axis is
  also the practical ceiling, because the leaning walls print at ~45°, the classic FDM limit.
- **Anchor what the stock crops.** Near the perimeter, the vertical columns of sheared space enter
  the block through a *side face*, not through the floor. A protruding feature there (a key tab)
  can end up connected to nothing once the stock box crops its leaning prism — it becomes a
  watertight but *floating* fragment, invisible to most mesh checks. The fix is structural: run
  every key tab into an **interior anchor rail** (same width, several mm inward, unioned before
  the clearance offset), so the visible tab is just the end of a solid internal rail — exactly
  like the tongue of a real sliding dovetail. And always verify the **body count**: each finished
  part must be one connected solid (Part 10).

## Part 7 — The reference design

The verified object completes the Part 3 project (straight extrusion line; for the "nice, creative
curve" upgrade and its extra constraint, see Part 12). All values are parameters and can be changed.

| parameter | value |
|---|---|
| stock | 100 × 100 × 15 mm |
| extrusion direction **d** | (0.7, 0.7, 1) — 44.7° from vertical, at the FDM 45° print limit |
| seam band height | z = 7.5 mm on all four faces |
| key (per face, centered) | trapezoid: 12 mm wide at the band, 20 mm at the top, 4 mm tall — solid tab ~2.8 mm deep; a 0.8 mm straight neck precedes the flare so the lip is ≥ 0.55 mm deep everywhere (DFM) |
| key anchor rail | 12 mm wide × 8 mm inward run per key, flat top at z 11.5 (Part 6 rule) |
| plateau | 45° (sheared) ramps from 68×68 @ z 7 to 60×60 @ z 11 |
| QR code | 29×29 modules, 1.24 mm/module, relief +1.2 mm, payload `Congratulations Francesco! UofT '22` |
| title / subtitle | relief +1.0 mm, DejaVu Sans Bold |
| clearance | ±0.15 mm per part (0.3 mm total gap) |
| signature | "pepi 2026", engraved 0.6 mm in the underside, mirrored to read from below |

The face profile — the "base shape for the half side" of Part 2, now dimensioned. The key belongs
to the bottom part and **flares upward**, so a straight vertical pull is impossible on every face,
while the flat band hides everything else. On the face the key merges with the bottom layer over
its full base width (it is the end of its internal anchor rail), exactly like a real dovetail:

Face seam profile

The parting surface, laid out as a plan in sheared coordinates. Each face key projects to a
quadrilateral just *outside* the z = 0 footprint (its prism leans back in through the face) and
continues inward as its anchor rail; QR and text are just black-and-white artwork dropped into
the plan:

Sheared-plan layout

The resulting bottom part, and the interface it hides:

Bottom part

Hidden interface from above

The top part is the exact complement (shown flipped, as it prints):

Top part, flipped

Assembled, exploded, and the single separating movement:

Assembled

Exploded along d

Separation sequence

From every side, the classic look — a mid-height seam with a small dovetail, identical on all four
faces (the 0.3 mm clearance shows as the thin joint line, as on any printed puzzle):

Four sides

A cross-section through the middle shows the whole mechanism at once — band, the two keys leaning
along **d**, plateau ramps, QR relief, and the uniform gap:

Cross-section

## Part 8 — Step by step in Autodesk Fusion

The construction from Part 6, translated to Fusion features. The strategy: model the **"Lower" solid**
(everything below the parting surface) once, parametrically, with a signed offset parameter `ofs`;
then obtain each part with one Combine against the stock box, evaluating `ofs` at −0.15 for the
bottom part and +0.15 for the top part.

**8.1 Setup**

1. New design, units mm. In **Modify ▸ Change Parameters** create user parameters:
   `L = 100`, `H = 15`, `band = 7.5`, `keyH = 4`, `keyW0 = 12`, `keyW1 = 20`,
   `dx = 0.7`, `dy = 0.7`, `railLen = 8`, `ofs = -0.15`.
2. **Stock**: sketch an L × L square on the XY plane, corner at the origin; Extrude `H`.
   Rename the body `Stock`.
3. **The direction path**: create a 3D sketch (Sketch ▸ Create 3D Sketch), draw a single line from
   `(-8, -8, -20)` to `(dx*40+8, dy*40+8, 40)` — a line along **d** extended well beyond the stock.
   Rename it `Path`. *Every* sweep in this recipe uses this one path; that is what guarantees all
   features share the same disassembly motion.

**8.2 The Lower solid**

4. **Base slab**: offset plane at z = −5; sketch a rectangle from (−30, −30) to (L+30, L+30);
   Extrude up to a height of `band + ofs − (−5)`, i.e. distance `band + ofs + 5`, as a **New Body**
   named `Lower`.
5. **Keys** (four sweeps, one per face):
   - Sketch on the front face plane (the XZ plane): draw the key trapezoid centered at x = L/2 —
     width `keyW0` at z = `band`, width `keyW1` at z = `band + keyH`. Apply a sketch **Offset** of
     `ofs` to the trapezoid (outward for positive).
   - **Create ▸ Sweep**, profile = the trapezoid, path = `Path`, extent: whole path, operation
     **Join** to `Lower`. The sweep makes the key an oblique prism along **d**; everything
     falling outside the stock is discarded later by the final Combine.
   - Repeat on the right, back and left face planes. Do **not** use a circular pattern — a pattern
     would rotate the sweep direction, which must stay identical for all four keys.
6. **Anchor rails** (the Part 6 rule — one per key; without these the printed tabs would be
   orphaned wafers). On an offset plane at z = `band − 1` sketch a `keyW0 + 2·ofs` × `railLen`
   rectangle, centered on the key's face position and starting just outside that face (for the
   front key at z = 6.5 and dx = 0.7: x from 44.4 to 55.6, y from −0.7 to `railLen` − 0.7 — the
   0.7 = `dy · (band − 1 − 6.5 + ...)` shift simply follows the Path; easiest is to project the
   swept key and snap the rectangle to its base edge). **Sweep** the rectangle along `Path`
   (Join), then **Split Body** with a plane at z = `band + keyH + ofs` and delete the part above,
   so the rail's top is flat and flush with the key top.
7. **Plateau**: offset planes at z = 7 and z = 11; on them sketch concentric centered squares 68×68
   and 60×60 (each offset by `ofs`); **Create ▸ Loft** between them, Join to `Lower`. (Even at the
   44.7° tilt of **d**, a 45° ramp still opens up during the motion — **d**·**n** > 0 on all four
   ramps — so this unsheared frustum satisfies the Part 6 rule.)
8. **QR + text**: on the z = 11 plane, **Insert ▸ Insert SVG** with the QR artwork, and use sketch
   **Text** (any bold font) for the title and subtitle. Select all profiles and **Sweep** them along
   `Path` (Join), then trim them flat: **Split Body** with an offset plane at z = 12.2 (QR) / 12.0
   (text) and delete the upper slivers. The sweep — *not* a vertical extrude — is what makes the
   relief walls parallel to **d**; a vertical extrude here would produce a part that jams (Part 6).
   Hand-offsetting hundreds of QR profiles by `ofs` is impractical; for a QR interface prefer the
   generator of Part 9, or accept a coarser relief (enlarge the modules and skip their offset —
   the 45°-equivalent gap of the plateau still dominates the fit).
9. **Signature** (optional): sketch mirrored text on the bottom face, Extrude −0.6 mm, **Cut**.

**8.3 The two parts**

10. Set `ofs = -0.15`. **Combine**: target `Stock`, tool `Lower`, operation **Intersect**, *Keep
    tools*, *New Component* → export this body as `U3T_bottom`.
11. Edit `ofs` to `+0.15` (the timeline recomputes every sketch and sweep). **Combine**: target
    `Stock`, tool `Lower`, operation **Cut** → export as `U3T_top`.
12. **Check before printing**: with both bodies at `ofs` mismatched (bottom at −0.15, top at +0.15 —
    keep the exported copies), run **Inspect ▸ Interference** on the assembled position, then Move
    the top body by `t·(0.7, 0.7, 1)/1.404` for a few values of t (e.g. 1, 5, 15 mm) and re-run the
    interference check each time. Every check must report zero interference. Also confirm each
    exported part is **one connected lump**: a Fusion body can silently contain disjoint lumps
    after a Combine — load the STLs in the slicer and check its object list shows a single solid
    per file (Part 6, second rule).
13. Export each part with **3D Print / Save as Mesh** (STL or 3MF, fine refinement).

## Part 9 — Step by step, automated (and what it fixes)

The repository root contains `u3t_generator.py`, a ~400-line parametric generator that performs
the whole construction of Part 8 in about ten seconds (Python 3.11; dependencies in
`requirements.txt`). It is the tool that produced the shipped STLs:

1. builds the QR, the title, the subtitle and the four key footprints as flat 2D geometry;
2. extrudes everything **vertically** in sheared space (band slab, key prisms, plateau frustum,
   QR and text reliefs) and unites it into the `Lower` solid — twice, with −0.15 and +0.15 offsets
   (lateral offsets via 2D polygon offsetting, vertical via the extrusion heights: this is exactly
   the inner/outer-matrix idea from Part 3, applied everywhere at once);
3. applies the shear matrix (x = u + 0.7·z, y = v + 0.7·z) — turning every vertical wall into a
   wall parallel to **d**;
4. intersects with / subtracts from the exact 100×100×15 stock using **watertight boolean
   operations** (the `manifold3d` kernel — the same class of robust engine that 3D Builder's
   "Repair" only approximates);
5. engraves the signature and writes the STLs plus a verification report.

Every intermediate object is a closed manifold solid at every step, so there is no red warning
frame, no "Repair", and no hours of mesh cleanup — the pipeline that fought back in Part 4 simply
disappears. Change any parameter at the top of the file (payload text, key size, direction **d**,
clearance, even the number of sides via the key table) and re-run.

## Part 10 — Verification: the printed object cannot be flawed by luck

"Be accurate" means: do not trust the construction, test the meshes that go to the printer.
`u3t_generator.py` runs this suite on its own output (results for the shipped STLs):

| check | result |
|---|---|
| bottom part watertight, consistent winding | yes — 89 932 mm³, exactly inside [0,100]×[0,100]×[0,12.05] |
| top part watertight, consistent winding | yes — 56 138 mm³, exactly inside [0,100]×[0,100]×[7.65,15] |
| **connected bodies per part** | exactly 1 and 1 — no floating fragments |
| assembled overlap (boolean intersection) | 0.000000 mm³ |
| slide along **d**, 14 stations t = 0.05 … 40 mm | 0.000000 mm³ overlap at every station |
| **control**: pull straight up 1 mm / 2 mm | collides (61.1 / 102.8 mm³) — the keys lock, hard |
| **control**: flat diagonal slide 1 mm / 2 mm | collides (341.1 / 863.3 mm³) — Roger's move does not open it |
| thin-feature scan (`dfm_scan.py`, FDM 0.5 mm rule) | no free-standing feature below 0.5 mm on either part; the only sub-0.5 readings are solid-backed chamfer edges where the key flanks meet the faces |

The two control rows are the puzzle property itself, demonstrated numerically: the naive motions
jam, the one intended motion sweeps through the entire disassembly without ever touching. The
body-count row exists because it once failed: an early draft with a near-vertical **d** (0.4)
and no anchor rails produced keys that were watertight, collision-clean — and *detached* (visible
as separated tabs in any mesh viewer). Watertightness alone does not catch that failure mode;
counting connected components does.

## Part 11 — Printing and assembly

- **Files**: `stl/U3T_bottom.stl` (print as oriented) and `stl/U3T_top_print.stl` (already flipped
  exterior-side-down). Both parts print **without supports**: the leaning walls sit right at the
  classic 45° FDM limit (44.7°), the ramps are gentler, and all reliefs face up on the bed.
- **Settings**: PLA, 0.2 mm layers (0.12 mm makes a crisper QR), 3 perimeters, ≥15 % infill.
  Enable elephant-foot compensation (~0.1 mm) or lightly deburr the first-layer edges — the band
  and the side faces must mate flush.
- **Fit**: the 0.3 mm total gap is a snug sliding fit on a well-tuned printer, in the spirit of the
  ±0.127 mm from Part 3 with a little extra for FDM reality. If it binds, sand lightly or reprint
  with `CLR = 0.20`; for a loose "demo" fit use 0.25.
- **Minimum feature policy (DFM)**: interface artwork uses an *asymmetric* clearance — the raised
  text and QR keep their full nominal width (every stroke ≥ 0.55 mm after a morphological
  opening), and the mating cavities take the whole 0.3 mm, with sub-0.5 mm walls between
  neighbouring letter cavities fused away. The key flare starts above a short straight neck so
  the lip depth never falls below 0.55 mm. The only sub-0.5 mm readings a wall-thickness checker
  will still report are the tapering solid-backed edges where the flared flanks meet the side
  faces — the printed result is a slightly rounded lip edge, present in every joint of this
  family, with no structural or fit consequence.
- **Assembly**: rest the top part over the bottom, offset about +10 mm in x and y, and lower it
  along the diagonal (45°); it seats flush with one smooth push. Because the lean of **d** breaks
  the square's symmetry, **only one of the four rotations engages** — a nice extra beat for the
  puzzle: the solver must find not only the motion but the orientation.
- **The reveal**: separate, and the plateau shows the title, the subtitle and the QR code. Relief
  QR codes scan best under raking light; a soft pencil rubbed flat across the module tops makes
  them scan instantly. To point it at the family album, put the URL in `QR_PAYLOAD` and re-run the
  generator (shorter URLs give coarser, easier-to-print modules).

## Part 12 — The "nice, creative curve", done right

Part 3 asked for a curved extrusion. The theory of Part 6 carries over: a constant-curvature
extrusion means the disassembly is a **screw motion** (rotation about an axis, possibly with pitch;
the straight line is the zero-curvature member of the family). Replace "lines parallel to **d**"
with "orbits of the screw motion", and the shear with the cylindrical unwrapping around the axis:
the parting surface must be single-valued along the orbits, walls must be surfaces swept *by* the
orbits (coaxial cylinders / helical ruled surfaces), and every side face must satisfy the exit
condition — the orbit velocity must point out of the face across the whole key.

One genuine subtlety, and the resolution of the Part 4 trap: wherever an orbit runs **parallel** to
the parting surface — for a horizontal rotation axis, this happens along the whole vertical plane
through the axis — a *flat* lid is tangent to the orbits, and the orbits curve down *into* it on
either side. A flat QR floor under a screw-swept box is therefore never exactly separable; it only
worked "so far" in Part 4 because mesh approximation and sanding absorbed the interference. The fix
is to curve the lid into a surface coaxial with the screw axis (bend the QR plane into a cylinder
patch) — or to keep the information on a flat plateau and give the *frame* the curve, which is the
compromise chosen for the verified reference object: provably correct today, curved edition ready
whenever the family demands a sequel.

## Part 13 — Files in this repository

| file | purpose |
|---|---|
| `docs/The-Unnamed-3D-Thingy.md` | this document |
| `docs/original-design-notes.pdf` | the original notes reproduced in Parts 1–4 |
| `docs/figures/original/*.png` | figures recovered from those notes |
| `docs/figures/gen_*.png` | figures generated from the actual shipped geometry |
| `docs/article/` | the same story told as an article, with its own images |
| `u3t_generator.py` | parametric generator + verification suite |
| `dfm_scan.py` | independent minimum-feature scan (Part 11) |
| `u3t_figures.py`, `tools/*` | figure, render and article tooling |
| `stl/U3T_bottom.stl` | bottom part, print-ready |
| `stl/U3T_top_print.stl` | top part, pre-flipped, print-ready |
| `stl/U3T_top.stl` | top part in assembly orientation (for CAD/inspection) |
| `verification/verify_report.json` | machine-readable results of Part 10 |
| `README.md`, `requirements.txt`, `LICENSE`, `NOTICE` | how to run it, and under what terms |

---

## Part 14 — The rotation edition: the "nice, creative curve", realized

Part 3 asked for the extrusion to follow "a nice, creative curve instead of a predictable and
boring straight line", and Part 4 attempted it with Blender's screw modifier before the notes
broke off. This chapter finishes that thread. The result is a second, fully verified pair of
printable parts with the same contract as the straight edition — identical dovetail seam on all
four faces, hidden QR + title interface, one single movement — except the movement is now a
**rotation**: the top part rolls open along circular arcs about an axis outside the block. A
circle is the constant-curvature curve the notes wanted; the straight line of Part 7 is just its
infinite-radius limit.

**14.1 Where the axis may go — three placement rules.** For a rotation about an axis **A**, the
orbits (the circles points travel along) replace the straight lines of Part 6, and the parting
surface must be crossed at most once per orbit. That, plus the requirements of the puzzle, pins
down where the axis can be:

1. **Not parallel to any side face** — otherwise the two faces parallel to the orbit planes can
   only carry grooves that surface on those faces, spoiling the identical-faces illusion. This is
   exactly the constraint stated in Part 2. So the axis runs **diagonally** in plan.
2. **The apex plane must miss the block.** The vertical plane through the axis is where orbits
   turn around (rise on one side, fall on the other). If it crosses the block, flat surfaces are
   crossed twice by some orbits and the parts jam — the Part 12 trap, and the hidden reason the
   Part 4 Blender attempt kept feeling harder than it should have. Placed so the apex plane
   clears the block, every orbit rises monotonically through it, and the flat band, plateau and
   relief tops of the straight edition become legal again exactly as they are.
3. **Far enough away to homogenize the slopes.** Orbit steepness varies across the block: shallow
   near the apex side, steep far from it. The axis distance is chosen so that over every
   wall-bearing region the orbit slope stays between ~43° and ~61° — walls lean at most ~46° from
   vertical (printable) and the keys keep useful depth on all four faces.

Axis placement

**14.2 The chosen geometry.**

| parameter | value |
|---|---|
| axis **A** | direction (1, 1, 0)/√2, through the point (105, −105, −103.5) |
| apex plane | x − y = 210 — about 100 mm beyond the nearest block corner |
| arc radius at block center | ≈ 185 mm (grooves visibly curved: ~7 mm of sagitta across the block) |
| opening motion | ≈ 12° of rotation frees the parts (verified clean out to 25°) |
| key (per face, centered) | 12 mm at the band → 20 mm at the top, **4.5 mm tall** (7.5 → 12.0), with a 1.3 mm straight neck before the flare (DFM: lip depth ≥ 0.55 mm even on the shallow faces) |
| key anchor rails | 12 × 8 mm, as in Part 7 |
| plateau | flat top 60 × 60 at z = 11, **orbit-swept curtain walls** (no 45° ramps) |
| QR / title / subtitle / clearance / signature | identical to Part 7 |

The construction is the Part 9 pipeline with one substitution: the linear shear becomes the
**bend map** — vertical design lines map onto orbits, so every design-space prism turns into a
curved-wall solid that slides along the rotation by construction. Two implementation details
matter. First, every footprint is defined as the **pre-image** of its true real-space position
(face trapezoids sampled on their faces, QR and text taken at the z = 11 content plane), so the
face seams come out exactly straight and the QR lands undistorted — naively drawing them in
design space would smear them by the varying orbit drift. Second, below the band the interface is
just the flat plane z = 7.5, so the slab is left as a plain straight box; bending it would only
introduce faceting error where none is needed (a sagging bent-cap facet was, in fact, the one bug
found and fixed during this chapter's verification).

**14.3 The result.**

Rotation bottom part

Rotation hidden interface

Rotation top part

The one movement — a roll about the far diagonal:

Rotation separation sequence

Rotation exploded

From outside, nothing gives the curve away — the four faces still show the same band and key:

Rotation four sides

Rotation cross-section

**14.4 What the curvature costs.** Two honest deltas against the straight edition. Key depth is
no longer equal on all faces: depth per millimetre of key height equals the ratio of the orbit's
face-normal component to its vertical component, which grows toward the apex — the two faces
nearer the apex get ~3.2 mm deep tabs, the two farther faces ~2.0 mm (the key was raised to
4.5 mm tall to keep the shallow pair robust; all tabs remain rail-anchored solids per Part 6).
And the plateau uses orbit-swept curtain walls instead of 45° ramps — with the slopes homogenized
by rule 3 these lean 29°–46° from vertical, so both parts still print support-free, but the
interface silhouette differs slightly from the straight edition's pyramid look.

**14.5 Verification** (same suite as Part 10, motion replaced by the rotation):

| check | result |
|---|---|
| bottom part | watertight, 1 body, 88 380 mm³, exactly [0,100]×[0,100]×[0,12.05] |
| top part | watertight, 1 body, 57 572 mm³, exactly [0,100]×[0,100]×[7.65,15] |
| assembled overlap | 0.000000 mm³ |
| rotation about **A**, 12 stations 0.05° … 25° | 0.000000 mm³ at every station |
| **control**: pull straight up 1 / 2 mm | collides (128.5 / 227.6 mm³) |
| **control**: flat diagonal slide 1 / 2 mm | collides (416.3 / 926.1 mm³) |
| **control**: the straight-edition slide **d** = (0.7,0.7,1), 2 / 5 mm | collides (282.1 / 73.8 mm³) — the curve is load-bearing: the old move does not open the new puzzle |
| **control**: reverse rotation 1° | collides (21 424 mm³) |
| thin-feature scan (0.5 mm FDM rule) | clean on both parts except the same solid-backed flank chamfer edges as Part 10 |

**14.6 Printing and playing.** Print exactly as in Part 11 (`U3T_rot_bottom.stl` as oriented,
`U3T_rot_top_print.stl` pre-flipped; no supports; same 0.3 mm total clearance). To open: hold the
bottom part and roll the top away over the corner between the front and right faces — a rolling
wrist motion about a horizontal diagonal line ~185 mm outside that corner. Only one of the four
orientations engages, and unlike the straight edition even the correct orientation refuses a
straight pull: the solver has to discover a *curved* motion, which is a satisfying extra step.
Solvers who met the straight edition first will find their old move jams (see the control row) —
the two objects look identical from every side and open differently, which makes the pair itself
a nice demonstration of just how large this family of solutions is.

**14.7 New files.**

| file | purpose |
|---|---|
| `u3t_rot_generator.py` | rotation-edition generator + verification suite |
| `u3t_rot_figures.py` | rotation-edition figures |
| `stl/U3T_rot_bottom.stl`, `stl/U3T_rot_top_print.stl` | print-ready parts |
| `stl/U3T_rot_top.stl` | top part in assembly orientation |
| `verification/verify_report_rot.json` | machine-readable results of §14.5 |
| `docs/figures/rot_*.png` | figures of this chapter |

*pepi's notes, completed August 2026. The U3T finally has everything except a name.*

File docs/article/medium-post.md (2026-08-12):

# The Unnamed 3D Thingy

## A wooden-block riddle, the family of infinite answers hiding behind it, and a 3D-printed gift with a secret inside

Years ago, my boss shared with me a book he wrote about critical thinking. One of its mental
exercises has been living rent-free in my head ever since. It goes like this:

> There is a block made of two different kinds of wood, mated so perfectly that there is no air
> between them. From every side, the assembly looks exactly the same: a seam at mid-height, with a
> small dovetail key in the middle of each face. The two layers can be separated with a single
> simple movement — no glue, no springs, no tricks. The same movement puts them back together.
>
> How?


*The block. All four sides look like this. The dovetails say "you can't lift me"; the puzzle says otherwise.*

The dovetail on the front face says the top can't be lifted. The dovetail on the side face says it
can't slide sideways either. Every face you check makes the object more impossible. That's the
charm.

## The official answer

The solution in the book is the one beautifully modeled by Roger: the dovetails aren't dovetails.
They're the *ends of straight grooves* that run diagonally through the block, at 45° to every
face. Slide the top along that diagonal and it glides right off, while every individual face
insists to the end that no such motion exists.


*Roger's solution: two straight diagonal grooves. I really love it.*

## Not "the" solution

My observation back then — which I kept rummaging over for years — is that this is not *the*
solution, because the problem admits infinitely many. To prove the point, I built a different one
in 3D Builder, where the grooves are *arcs* instead of straight lines, had it printed, and gave it
to my boss as a semi-parting gift when he semi-retired.


*My counter-example: the same four keys, but the grooves curve. The top comes off with a twist instead of a slide.*

Roger's straight grooves and my curved ones belong to one family: two grooves, each connecting a
pair of side keys, sweeping around a center that can sit anywhere from near the middle of the
square, to a corner, to infinity — where the arcs straighten into Roger's diagonals.

An infinite family, then. But a *cramped* one: two grooves have to cross the whole block, so the
shape is essentially forced. There is no room in it for anything else. In particular, there is no
room for *information*.

## Grooves on three axes

That bothered me, so I gave it more thought, and found we can do much better — the key is to stop
moving in a plane and start moving along all three axes.

Take the outline of the block's four sides — call it the *polygon box* — with a dovetail key drawn
on each side, and extrude it along a line that is oblique to *everything*: not parallel to any
face. Because the direction has components along all three axes, **each side gets its very own
groove**, independent of the other three. No more two-grooves-crossing-the-block. The four keys
are now just the visible ends of four short, private ramps.


*The polygon box after the oblique extrusion, cropped to the block: every side carries its own groove.*

Two consequences fall out immediately:

1. **The square is no longer special.** Three sides, five, seventeen — every side brings its own
   groove along, so any polygon works.
2. **The middle of the block is suddenly free real estate.** Once the perimeter does its job, the
   rest of the hidden surface between the two parts can be *anything* — which means it can carry
   an arbitrary amount of information. A message. A portrait. A QR code.

My quick proof-of-concept, "Hello!":


*The bottom part of the Hello block: four keys on the rim, and a whole plateau of free space in the middle.*

## Where I got stuck

Then came the family graduation, and the plan wrote itself: a 100 × 100 × 15 mm block for
Francesco — title, subtitle, and a QR code hidden on the inner surface, with the extrusion running
along "a nice, creative curve instead of a predictable and boring straight line."

The execution did not write itself.

My pipeline was 3D Builder for the solids and Blender for the sweep — the screw modifier, bending
the polygon box along an external axis:


*The screw modifier doing its thing. Pretty — and, as I would learn much later, subtly dangerous.*

It produced lovely curved surfaces and a trail of problems. 3D Builder drew red warning frames
around the imported meshes; its "Repair" function fixed them by *changing the geometry*. The
boolean cleanups refused to cooperate:


*Trying to trim the QR floor to the curved frame. The excess would not come off.*

Hours of manual mesh surgery later I had a cutting box I *hoped* would produce two mating parts —
"in the worst case I'll have to sand them a little." I saved one render because it looked cool,
and the notes stopped there.


*The last image in my notes. It stayed the last image for four years.*

## The missing piece was a change of coordinates

What the project needed wasn't better mesh surgery. It was a proof.

Suppose the two parts separate by sliding along a fixed oblique direction **d**. When is a
proposed parting surface actually valid? Here's the whole theory in one move: **shear the world so
that d becomes vertical.** In sheared coordinates, u = x − d₁·z, v = y − d₂·z, the separating
motion is straight up — and a surface can be slid off vertically exactly when it is a plain
height field: one z per (u, v), cliffs allowed.


*Left: the real block, where every wall must lean along d. Right: the same block in sheared coordinates, where d is vertical and any height field is a valid parting surface.*

That single sentence settles everything the notes had left hanging:

- **Any information fits.** Take any relief — QR code, text, a portrait — extrude it straight up
  in sheared space, shear back, done. The walls come out parallel to **d** automatically. No angle
  checking, ever. (My old rule of thumb, "features must be flatter than the cutting box," was a
  shadow of this — necessary, not sufficient.)
- **The four faces stay identical.** The band and the keys are drawn on the faces, exactly as the
  puzzle demands, and swept inward along **d**:


*The face profile, identical on all four sides. Band at 7.5 mm; a key 12 mm wide at the base, 20 at the top, 4 tall, standing on a short 0.8 mm neck — the neck's story comes later.*

- **The whole design becomes a drawing.** Here is the entire parting surface as a plan in sheared
  coordinates — four keys with their anchor rails, a plateau, and the hidden payload, which is
  literally just black-and-white artwork placed on the plan:


*The parting surface as a plan. The gold shapes are the four keys; everything dark is information riding along for free.*

So this time the object wasn't sculpted; it was *computed*. A small script builds both parts from
the drawing above — with a 0.3 mm clearance built in the same way my old notes built the
inner-and-outer "matrices", just applied everywhere at once — and produces watertight,
print-ready meshes in seconds instead of evenings.

## The proof of the pudding

Computed is nice. *Verified* is better — the same script then attacks its own output:

- both parts are watertight, single-piece solids that fill the exact 100 × 100 × 15 stock;
- assembled, their overlap is 0.000000 mm³ — and it stays exactly zero at fourteen positions along
  the entire slide-out path;
- and, my favorite part, the *negative controls*: pull the top straight up and the simulation
  reports a solid collision — the keys lock. Try Roger's flat diagonal slide: collision again.
  The puzzle property isn't an impression, it's a measurement.


*The verified block. From here it's just a two-tone slab with dovetails.*


*All four faces, orthographic. Same band, same key, everywhere — the 0.3 mm joint line is the honest look of a printed puzzle.*

Slide it along the one direction it never admits to having, and:


*One movement. The keys clear their sockets and the interior starts to show.*


*Fully open.*

And the reveal — the reason the middle of the block was worth liberating:


*The hidden interface: a QR code (it scans; raking light helps), a title, a subtitle. None of it visible from outside.*


*The top part carries the same story in negative.*

A cross-section shows how it all stacks up — band, keys leaning on their rails, plateau, QR
relief, and the uniform clearance gap between the two colors:


*Cross-section through the middle of the block.*

## What the first print taught me

Full disclosure: the first version of this design was flawed, and a mesh viewer caught it before
the printer did. Viewed from below, two of the dovetail keys floated free of the body — watertight,
collision-clean, and attached to *nothing*.

The cause is worth remembering. A key leans along **d**; the block's face crops it; and if the
lean is shallow, the crop takes the key's entire root with it. Every standard mesh check passes —
watertightness says nothing about your model being in one piece. Two rules came out of that
morning:

1. **Depth costs lean.** A key h mm tall can only stick out `lean × h` millimetres from the face.
   Near-vertical extrusions make wafer keys, no matter how you draw them. This design leans a full
   45° — which is also exactly what an FDM printer will tolerate without supports. That is not a
   coincidence; it's the design sitting on both limits at once.
2. **Anchor what the crop can orphan.** Every key continues inward as a solid rail, so the visible
   tab is the *end* of an internal beam, like the tongue of a real sliding dovetail — and the
   verification suite now counts connected bodies, because "watertight" and "in one piece" are
   different promises.

I thought that was the end of the humility. Then the files went to a printing service, and their
manufacturing review found two things my entire verification suite had happily blessed: walls a
tenth of a millimetre thick between neighbouring letter cavities — my clearance shaved every
stroke from both sides, and where two letters nearly touch, the material between their sockets
all but vanished — and key lips tapering below half a millimetre right where the flare begins.
Both fixes are in the published files: the artwork now takes its clearance *asymmetrically*, so
the raised letters keep their full width and the cavity absorbs the whole gap, and every key
stands on a short straight neck so its lip starts life a comfortable 0.55 mm thick (that's the
neck in the face-profile drawing above). Hence rule three: **verified is not the same as
manufacturable.** Geometry can be provably correct and still contain features no nozzle can
make — check minimum feature size the way the print shop will, because they will.

## The curve, done right at last

One thing remained from the graduation wish list: the *nice, creative curve*. A constant-curvature
extrusion means the opening movement is a rotation about an external axis — the straight line is
just the member of the family whose radius is infinite. My Blender attempt had chased exactly
this, and the shear trick explains precisely why it fought back: rotation bends the rules.

Three placement rules make it work:

1. the axis must run **diagonally** in plan — orbit planes parallel to a face would force grooves
   to surface on that face and spoil the identical-faces illusion (my old notes had guessed this
   constraint without knowing why);
2. the **apex plane** — the vertical plane through the axis, where orbits turn around — must miss
   the block entirely. If it crosses, flat surfaces get visited twice by the same orbit and the
   parts jam. *This* was the silent killer inside the screw-modifier build: a flat QR floor under
   a curved frame is never exactly separable if the axis sits underneath it.
3. the axis must sit **far enough away** that the orbit slopes stay printable everywhere a wall
   lives.


*The rotation edition's geometry: a horizontal axis along the plan diagonal, about 15 cm outside the block. Every orbit rises monotonically through it; ~12° of rotation opens the parts.*

With those rules, the same pipeline builds a second, fully verified pair of parts — same identical
faces, same hidden payload, but the walls now curve along circular orbits and the block opens with
a rolling motion over one corner:


*The rotation edition opening. Note the tilt — this is a genuine rotation, not a lift.*


*Open, at 14° of rotation.*


*Same secret, curvier custodian: every wall in this picture is a patch of a cylinder around the distant axis.*


*And still: four faces, one look. You cannot tell the two editions apart from the outside.*

The controls got a new row, and it's my favorite measurement of the whole project: applying the
*straight* edition's opening move to the *rotation* edition jams solidly. Two objects,
indistinguishable from every side, each refusing the other's solution — a fitting way to
demonstrate just how large this family of "the" solution really is.


*The rotation edition in cross-section: same anatomy, gently curved bones.*

## Coda

The blocks print without supports — the bottom parts as they are, the top parts flipped on their
backs — in PLA at 0.2 mm layers, with a 0.3 mm built-in clearance that lands somewhere between
"satisfying" and "sand it a little", exactly as the original notes budgeted. Only one of the four
orientations engages; the other three are part of the puzzle. The full technical write-up — the
math, the step-by-step CAD walkthrough, the parametric generator, and the verification logs —
lives alongside the printable files *[here](https://github.com/pepistrafforello/U3T)*.

The gift finally exists twice over, four years late and provably correct, which I choose to call
even. It has a dovetail on every face, a rotation nobody can see, Francesco's name hidden in the
middle — and still, after all this time, no name of its own.

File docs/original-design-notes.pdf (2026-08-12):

# The Unnamed 3d Thingy

Years ago, my boss shared with me a book he wrote, in digital format; its main topic is critical thinking training. There is a section about a mental exercise, that I am summarizing as follows:

There is a block composed of two different types of wood, each about an inch in height, that were mated in a manner that ensured no gaps of air between them. From every side, the assembly looks the same:


The two layers of wood can be separated from each other by a single simple movement, there is no glue or any other adhesive or mechanical inhibitor involved. They could be reunited with the same type of motion.


In the book, the solution to this puzzle is exactly the one beautifully designed by Roger:

(I really love it!)


My observation back then, which I rummaged a bit more over time, is that this is not the solution, because in fact the problem admits infinite solutions. To prove it, I created a different one using 3D Builder on Windows, I had it 3D printed and gave it to my boss around Christmas as a “semi-parting” gift, as he is semi-retiring:

As it can be easily verified, Roger’s solution and mine belong to a family of solutions which consist of two grooves each connecting one of the side keys to another, where the center of the curve that they describe can be arbitrarily set from somewhere between the middle of the square and one of the corners, then to a corner (as in my solution), then the beyond the corner all the way to infinity (Roger’s solution).
There are of course infinite solutions in this family, but they are still very much limited in their shape; in particular, there is no additional information that can be encoded in the shape itself.

After giving it a bit of thought, I found out that we can do much better than that.
In fact, any amount of information, such as, for instance, QR codes or Roger’s portrait, can be encoded inside the apparatus without violating the requirements. Furthermore, the method can be extended from four to any number of sides >= 3.
In a nutshell, the process is as follow:
- define a base shape for the half side


- mirror it to generate a full side
- compose the sides to build the "polygon box" of choice, a square in this example but of course it can be anything >= 3


- extrude the box along a line with constant curvature, which can be arbitrary with some constraints, e.g. it cannot lie on a plane that is parallel to any of the sides. In this example, the extrusion is carried out along a straight line that is not parallel to any of the axes of the square prism, but it could be any other from an infinity of possible curves


- compose the 3d boundary box for the complete assembly, that is, a prism that matches the contour of the "polygon box" and extends to surround the volume of the missing element
- crop the extrusion using the boundary box


Now, all the mandatory features are implemented; all we are left to do is to place a “lid” on top of the box, and then create the complementing part by filling the space below. That means that we still have a lot of degrees of freedom in designing the rest of the boundary between the two parts, and thus we could encode an arbitrary amount of information there.
The key difference between this method and the solutions mentioned at the beginning of the document is that, by moving along three axes instead of two, we were able to give each side its own independent groove, which in turn makes it possible to change arbitrarily the number of sides.


Putting it all together, I built a quick complete example using Blender up to the step above, and then assembling it with 3D Builder, using .stl for the exchange:

A graduation U3T (“Unnamed 3D Thingy”) for Francesco

Based on the above, we have a little project for the upcoming graduation in the family - I know, it sounds impossible! I wonder, could it be reused elsewhere? ;)

The basic idea: starting from the “Hello” design in the previous page, adding two enhancements:
- Carrying out the extrusion of the "polygon box" along a nice, creative curve instead of a predictable and boring straight line
- Maximize use of the available space in the box, including the following elements:
- A nice title “Francesco Strafforello”
- Subtitle “University of Toronto ‘22”
- QR code (will point to a family album online)
- (only if feasible) other cool geometric elements TBD
- To account for engineering tolerance, we create two slightly different matrices, inner and outer (I’d rather stay out of gender references)

1 - matrix
The dimensions of the final product will be mm 100x100x15
Construct using 3D Builder

Tolerance guidance (from Xometry handbook):


Given the dimensions of our project, it seems that applying a tolerance of ± 0.005” = 0.127 mm everywhere might work.

To introduce tolerance, we modify the construction process described above. While we were going through the extrusion process for one of the mating parts, and filling the remaining space to obtain the other one, now we are going to extrude the tolerance space, and then using the free space on either side to obtain the actual parts. With that in mind, we start by creating the matrix as the difference between the inner and the outer one.


Inner matrix:

Outer matrix:

The difference in the longer side (0.15 instead 0f 0.127) is adopted to make extra room for diagonals and various curves.

In the end, the new matrix is simply composed of three thin rods joined together:


And this is our “polygon box” - that is, the apparatus before the extrusion:

Thus far, I have used 3D builder. Now I export the model in .STL format, to perform the extrusion with Blender. After a few attempts, I found that rotating the polygon box and applying the screw modifier along an external object I could get a nice, curved surface (external object is the elongated cuboid in the background):


After exporting the component to .stl, and importing it back to Builder 3D we can obtain this scene:

The green cuboid is the final volume for the apparatus, the blue one is the imported artifact. Note the red square around it, something in its geometry seems to be problematic for 3D builder; but, activating the “Repair” function actually alters its geometry. I’m trying to go ahead as it is, everything seems to be working so far. Checking out the intersection of the two artifacts:


Everything seem to be correct from the opposite side as well:

Next step: I need to add a bottom to my “cutting box” - the blue shape, that is.
The bottom is where I want to add some hidden information - in this case, a QR code pointing to Francesco’s LinkedIn profile. I generated the QR code using QRmonkey.org, but I could have used the sharing feature in Chrome, etc., then I loaded in 3D Builder and gave it a bit of 3D relevance (see https://www.youtube.com/watch?v=plvNbWHi84Y)


I am making sure that the angles of the 3D features in the bottom QR-code image need to be flatter than whatever angles will come from the “cutting box”:

Working inside 3D Builder I was able to join the bottom with the QR code and the cutting artifact, but I could not manage to cleanup the material in excess from the bottom:

So I exported the shape to STL and loaded it in Blender.


Then, with some hours of mesh work in Blender, I completed the cutting box which now includes the bottom with QR code:

Since this shape has been entirely generated using a base shape that has a slightly larger width than the known material tolerance, I can hope that removing it from the base box I will get two mating parts; of course, the mesh is always an approximation but I can hope that in the worst case I’ll have to sand them a little.

OK, I’m saving this one just because I think it is cool:

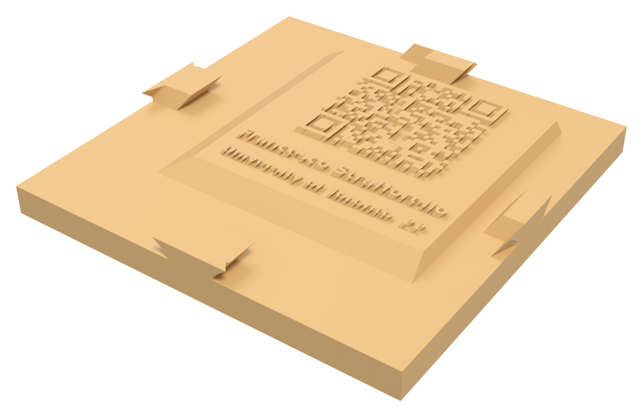
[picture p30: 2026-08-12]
docs/article/images/r3_bottom.png

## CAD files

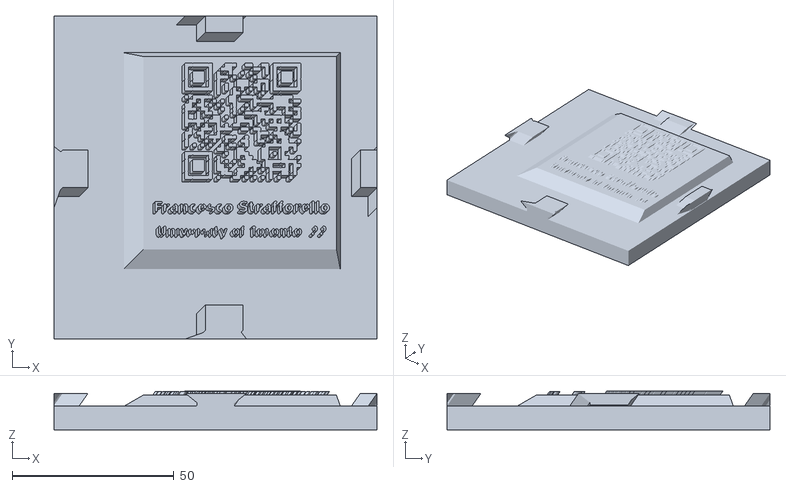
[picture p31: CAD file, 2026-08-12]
stl/U3T_bottom.stl
100.0 x 100.0 x 12.1

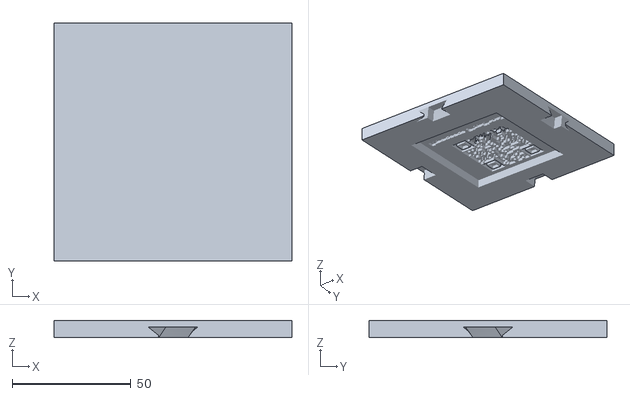
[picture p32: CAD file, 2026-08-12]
stl/U3T_rot_top.stl
100.0 x 100.0 x 7.35

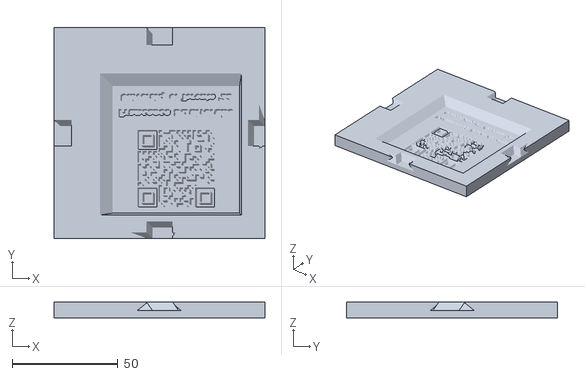
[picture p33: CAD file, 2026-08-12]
stl/U3T_top_print.stl
100.0 x 100.0 x 7.35

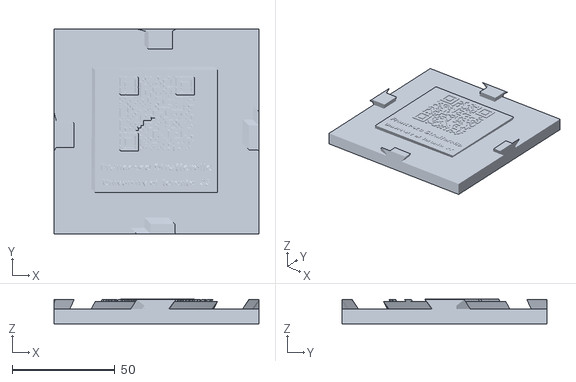
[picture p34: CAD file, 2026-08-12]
stl/U3T_rot_bottom.stl
100.0 x 100.0 x 12.1

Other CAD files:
stl/U3T_top.stl
stl/U3T_rot_top_print.stl

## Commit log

2026-08-12 U3T: parametric generator, verification suite and printable files
    A family of two-part solids that show an identical dovetailed seam on every
    face and come apart with a single movement. The parting surface is designed as
    a height field in sheared coordinates, which makes separability true by
    construction rather than by trial.
    Contents:
    * u3t_generator.py straight edition (translation along d = (0.7, 0.7, 1))
    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
    [U3T_bottom.stl, U3T_rot_bottom.stl, U3T_rot_top.stl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]
2026-09-13 Anchor each key rail on its inboard-most edge
    The first printed pair came back with two of the four dovetails worn thin. The
    cause was the anchor rail, which was always built from the trapezoid's base
    edge. That is correct only on the two faces d leans into. On the other two the
    base edge is the outboard one, so the rail was cropped short, drifted 3 mm
    sideways, and left the flare cantilevered: 0.20 mm of material across 16 mm of
    width with nothing behind it.
    Anchoring instead on whichever trapezoid edge lies furthest inside the block
    picks the base edge on one pair and the flare's top edge on the other, so those
    two keys now get a rail as wide as the flare itself, butted against its back.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
2026-09-13 Carry the face-shadow rule into the rotation edition
    The rotation edition inherited the same defect as the straight one, and worse:
    all four rails anchored on the trapezoid base, so the flare was cantilevered on
    the two faces the orbits leave through, and the rails broke the surface of the
    faces by up to 0.93 mm -- nearly twice the straight edition's error.
    The rule carries over; only its arithmetic changes. The design plan here comes
    from a bend map rather than a shear, so the inboard direction cannot be read off
    a normal vector. inward_plan_dir() measures it instead, by pre-imaging a point on
    the face and the same point 1 mm inside; anchor_edge() then projects the
    trapezoid's two horizont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
2026-09-13 Tilt the interface plane toward the mating direction; blank the content
    The content plane was horizontal, which sits 44.7 deg away from perpendicular to
    d and costs twice over. Features on it are foreshortened by cos(44.7) = 0.71
    across the shear, and since relief walls must run parallel to d, every raised
    island drifts 0.99 mm sideways per mm of height: a 1.24 mm QR module with 1.2 mm
    of relief ended up with 0.05 mm of itself standing over its own base. That is
    the resolution the printed object could not hold.
    The plane is now a parameter, PLAT_TILT, set to 30 deg of the 44.71 that would be
    exactly normal to d. Drift falls to 0.263 mm/mm and a 1.24 mm module keeps
    0.92 mm of straight-throu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
2026-09-13 Rotation edition: a sawtooth fan of axis planes for the interface
    A single tilted plane is normal to the motion but runs out of a 15 mm slab almost
    at once, leaving a canvas 12 mm wide. Many canvases in a sawtooth recover the
    area, and the rotation case makes that unusually clean: a plane through the
    rotation axis is perpendicular to EVERY orbit it meets, since its tangent space
    is spanned by the axis direction and the radius and the orbit velocity is normal
    to both. So each facet is exactly normal to the motion everywhere on it, and the
    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
2026-09-13 Drawing templates for the five canvas facets, and an artwork importer
    Five millimetre-true SVG templates, one per facet, plus one sheet carrying all
    five. The shapes are read off the built mesh rather than recomputed, so each is
    exactly the surface that exists: clearance, curtain and printable-angle trim are
    already taken off.
    Each facet is flat, and on it the pair (w = distance along the rotation axis,
    rho = distance out from it) is orthonormal -- so millimetres on the page are
    millimetres on the part. The risers sit at constant rho, which means they occupy
    NO width in that coordinate: laying the facets side by side in rho gives one
    continuous sheet, which is also what a viewer sees lookin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
2026-09-14 Protect drawn templates, and check artwork against the facet it sits on
    Regenerating the templates would have silently overwritten a template someone had
    already drawn on -- which is exactly what had happened to canvas_combined.svg.
    write_svg() now refuses to replace a file whose artwork layer has anything in it
    unless --force is passed, and this commit carries that drawing (an isometric cube
    logo, work in progress).
    The checker was also too quiet and, where it did speak, wrong:
    * it never looked at the facet, so artwork could be off the canvas entirely and
    still pass. templates.json now carries each template's outline in page
    millimetres, and svg_content.py checks containment an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
2026-09-14 The Terrier CDP lockup, laid out across three facets
    Text above, cube in the middle, text below -- which the geometry forces anyway,
    since only facet 3 has usable strips on both sides of it.
    facet 4 Terrier CDP Century Gothic Bold, 7.18 mm cap
    facet 3 the cube 12.5 mm, silhouette plus three edge grooves
    facet 2 Titan Technologies Century Gothic Bold, 4.35 mm cap
    Font chosen by measurement, not taste: of the modern faces installed, only
    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
2026-09-14 Raise the lockup off the facets, the cube as a real pyramid
    CONTENT_R is on. The artwork is read from the facet templates and raised along
    the motion; because each facet is already normal to the motion, a relief that is
    a height field over the facet is automatically one in the design plan, so there
    is no angle to check. Text gets one cap plane parallel to its facet. The cube
    gets three, tilted to meet at an apex, and the lower envelope of those three is
    the near half of a cube squashed onto the surface.
    text 0.80 mm nominal, 0.65 after clearance, measured 0.65
    cube 1.10 mm apex, 0.95 after clearance, measured 0.95 at the apex,
    0.43 at the edge corners, 0.00 at the corners b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
2026-09-14 Verify the STL files, not only the meshes in memory
    U3T_rot_top_print.stl was shipping with six non-manifold edges while the mesh it
    was copied from verified watertight, and nothing in the suite noticed, because
    the suite only ever looked at the mesh in memory.
    The mesh in memory and the file on disk are not the same object. STL stores
    float32, whose grid spacing at 100 mm is about 6 um, and the boolean kernel
    leaves the occasional vertex pair half a micron apart -- harmless in double
    precision, five such pairs in the rotation top. Flip that mesh into print
    orientation and the pairs land on different sides of the rounding: they collapse
    onto one point, and the faces that used both tear open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
2026-09-14 README: the sawtooth interface, the relief, and the numbers as they are now
    The README still described a flat plateau carrying a QR code, which neither part
    has carried since the fan went in. It now covers what is actually built.
    New section, "The hidden interface: a sawtooth fan" -- why a plane through the
    rotation axis is perpendicular to every orbit it meets, how that turns into five
    facets separated by risers at constant radius, the table of what each facet is
    worth (3553 mm^2 in total), and the two properties that govern drawing on it:
    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
2026-09-14 Weld at the precision the STL file will have, not above it
    The 5 mm cube trial tore the print copy again: watertight=False, straight past
    the weld added this morning. That weld picked a tolerance -- 1e-5 mm -- and the
    float32 grid at 100 mm is 7.63e-6 mm. Choosing a number the same order as the
    grid is guesswork, and it held only until the geometry changed.
    So stop choosing. Quantise the vertices to the output grid FIRST, then merge
    exactly: whatever the file cannot tell apart is fused before it is written, by
    construction and at any geometry. Then drop only the faces that gain a repeated
    index, which is still the one removal that cannot open a hole.
    h0_95 flipped, as float32 -> waterti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
2026-09-14 The cube at 3 mm: a third of a real one, which is enough
    At 0.95 mm the cube was 10 % of a true cube and read as a hexagon with a crease.
    Seen down its diagonal a real cube's near corner stands sqrt(2) x the silhouette
    radius proud -- 9.42 mm for this 13.3 mm emblem -- so the first build was a tenth
    of the shape it was drawing.
    Built and rendered at 3 mm and 5 mm, two angles each, one camera aimed at the
    cube's centre ON THE FACET so the taller ones grow toward the viewer rather than
    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
2026-10-08 Scan at the process's rule, and write a print copy that cannot pinch
    Two pieces of hardening, both prompted by the SLS print coming back wrong.
    dfm_scan knew one number, 0.5 mm, because that is the FDM rule the first pair was
    printed to. The SLS partner needs 0.8 mm. Everything between the two was invisible
    to every check in this repository, and that is exactly where the failed keys were:
    0.0-1.1 mm of material, which clears 0.5 comfortably and fails 0.8. It now scans at
    both and prints them side by side, because the minimum wall belongs to the machine
    and not to the drawing. Its docstring also says plainly that a patch is a question
    rather than a verdict -- a horizontal slice cuts every ob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
2026-10-08 Straight-sided key: the flare could not be made thick enough, so it is gone
    The SLS pair came back with two of four keys incomplete. Xometry's partner quoted
    0.8 mm minimum wall; the feature measured 0.0-1.1 mm.
    The feature is the flare's WING -- the extra width on each side of a dovetail that
    widens as it rises. On two of the four faces nothing backs a wing but the face
    shadow, the strip of the design plan the side face sweeps as z runs over the key.
    A wing at lateral offset w first exists at the height the flare reaches w, and from
    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
2026-10-09 Check the exported file before reaching for the repair
    weld() is a repair: it snaps vertices to the float32 grid so that nothing the
    file cannot tell apart stays separate. Snapping can also do the opposite -- fuse
    two vertices that belong to DIFFERENT sheets of the surface and pinch a mesh that
    was already sound. Applied unconditionally it therefore breaks as often as it
    fixes, and on a fan whose facets come close to tangent it broke every time: a
    watertight top part came out of weld() with eleven bad edges, at every grid phase
    the nudge loop tried.
    So export_welded() now writes the mesh as it stands, re-reads it, and only welds
    if the FILE is what is broken. Nothing else changes: U3T_top_p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
2026-10-09 Move the axis in: the dovetail comes back, and the canvas pays for it
    The straight-sided key was buildable and had cost the object its premise -- a
    rectangular tab does not say "this cannot be lifted". Getting the flare back
    needed the axis to move, because of a conservation law worth writing down:
    canvas strip width x key wing thickness rate = fan depth / sqrt(2)
    Both come from the phase phi about the axis: the plan displaces tan(phi) per mm of
    height, which thickens the wing, while a facet's run over dz is dz/tan(phi), which
    is the strip. No key PROFILE trades between them -- that is why every reshape
    failed -- and only the axis does. The apex plane came in from x-y=210 to x-y=13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
2026-10-09 Let the flare run: the dovetail has to be visible to be a dovetail
    pepi looked at the part and said the dovetails were not back. They were not.
    KEY_FLARE_RUN was 0.5 mm, chosen at the old axis on the argument that a wing needs
    height above it to thicken, so open the flare at once. Measured on the face, that
    makes the key a rectangle with a lip at its foot:
    printed widens 11.7 -> 19.0 mm over 65 % of the key's height
    was widens 11.7 -> 16.7 mm over 5 %
    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
2026-10-09 Close the groove at the foot of two keys
    pepi spotted a thin horizontal line running along the foot of two of the four
    keys on the open part. It is real: a notch 0.45 mm deep and 0.3 mm tall, and it
    had been there since the keys were first built.
    It comes from the clearance being taken in two places that disagree at the seam.
    The bottom half's band slab drops its top to BAND_Z - CLR = 7.35; its key
    trapezoid lifts its foot to KEY_Z0R + CLR = 7.65. Between those two heights the
    face belongs to neither, and on the two faces whose orbits leave through them the
    prism behind that strip sits inboard, so the face is cut back there. On the other
    two it is flush -- which is why it showed on exactly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
2026-10-09 Let the fan reach the whole canvas again
    pepi pointed at a large flat triangle beside the strips on the open part and
    asked for the facets back. They were not lost to the axis move -- they were
    trimmed away by CANVAS_MAX_LEAN.
    canvas_footprint() cuts the canvas at the radius where a facet would lean past
    that cap, which makes the cap decide how much of the central area is canvas at
    all, not merely how the strips are divided. At 50 deg the trim line fell at
    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
2026-10-09 Put the dates on the empty wide strip
    Facet 3 was the largest facet of the five and carried nothing. "2019-2026" fits
    it at a 6.36 mm cap with 1.11 mm strokes -- 39 % above the 0.8 mm SLS minimum, so
    it is not a squeeze. Dropping the spaces around the hyphen is what buys the room:
    with them the same string only reaches a 5.70 mm cap and 1.02 mm strokes.
    The interface is a three-part lockup again, which is what it was before the axis
    move halved the canvas and the content came down to two pieces:
    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
2026-10-29 New emblem and text: a beret, Louis Andre III, -80-
    Same canvas, same geometry, different content.
    facet 4 a stylized beret, 13.2 mm across was an isometric cube
    facet 3 Louis Andre III, 5.9 mm cap was 2019-2026
    facet 2 -80-, 10.0 mm cap was CDP
    Three things had to be built rather than swapped.
    A DOME relief kind. The beret wanted to be a rounded protrusion, and the only
    shapes relief_solids could make were a plane and three planes meeting at an apex.
    cap_sphere() caps the extrusion with a ball instead, which is legitimate for the
    same reason the others are: the facet is already normal to the motion, so anything
    single-valued over the facet is single-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
